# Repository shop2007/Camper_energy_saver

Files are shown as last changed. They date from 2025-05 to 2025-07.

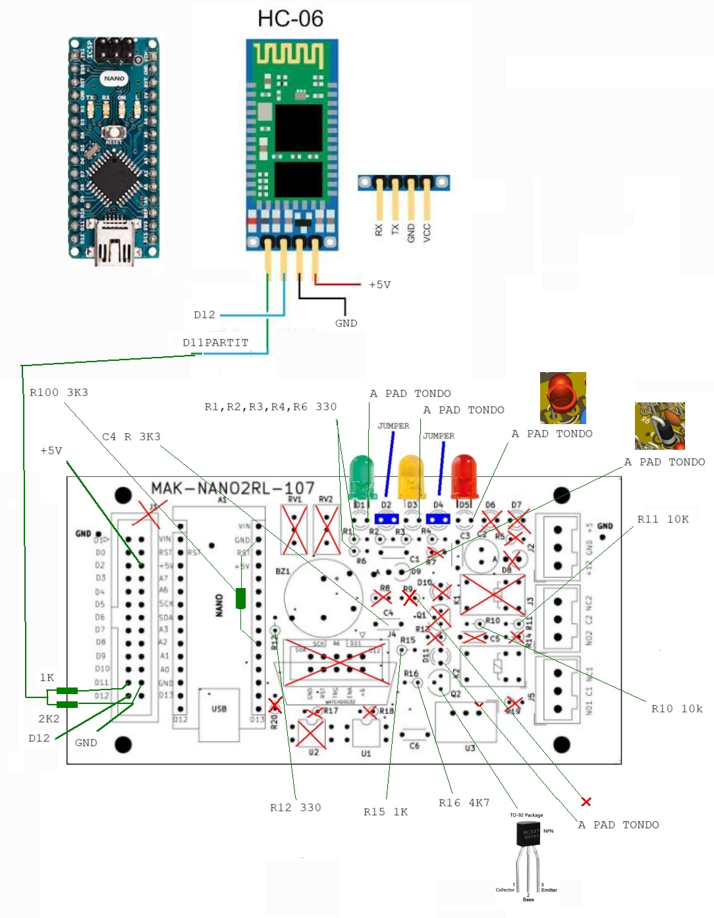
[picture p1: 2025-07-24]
PDF-immagini/MONTAGGIO-V4.jpg

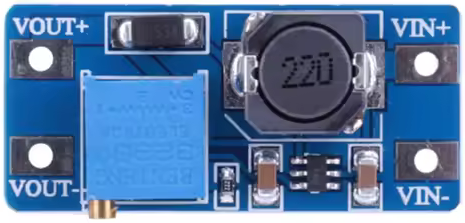
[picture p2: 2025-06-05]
PDF-immagini/MT3608 DC-DC Step-Up Booster.png

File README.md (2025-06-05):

# Camper Energy Saver

**Camper Energy Saver** è un sistema di gestione automatica della ricarica solare nei camper. Il dispositivo controlla la tensione della **batteria servizi** e, quando questa è completamente carica, **connette al charger solare** anche la **batteria di avviamento**, allo scopo di mantenerla completamente carica durante le soste prolungate.
Si possono impostare due soglie che controllano la batteria servizi, quella alta quando al charger solare verrà aggiunta la batteria motore, e quella bassa , quando la stessa viene staccata, per non sottrarre energia alla batteria servizi.

Lo stato del sistema viene trasmesso in tempo reale tramite **Bluetooth (HC-05)** a uno smartphone Android tramite l’app gratuita **“Bluetooth Terminal”**.

---

## ⚙️ Funzionalità principali

- Monitoraggio continuo della **tensione batteria servizi**
- Connessione automatica della carica solare alla batteria motore:
  - Priorità alla batteria servizi
  - Connessione della batteria motore solo quando la batteria servizi è completamente carica
- Segnalazione dello stato via **Bluetooth (HC-05)**
- Compatibilità con l'app Android **Bluetooth Terminal**
- Configurazione soglie tramite cavetto usb (e Arduino IDE) oppure da bluetooth terminal

---

## 🧰 Componenti hardware richiesti

- **Arduino Uno o Nano (ATmega328)**
- **Modulo relè 12V o 5V** (singolo o doppio)
- **Modulo Bluetooth HC-05**
- **Partitore resistivo** per misurare la tensione della batteria servizi
- **Diodi o relè di potenza** per instradare la carica
- **Alimentazione 12V** dal circuito servizi del camper

Al reset si accende semaforo rosso
Quando lampeggia velocemente il semaforo giallo è nel Menù
Quando lampeggia una volta al secondo è in RUN normale

******************************************
## 🧰 PROCEDURA DI CALIBRAZIONE 
- Entrare nel Menu (Nota1) digitando "Menu" ("M" maiuscola ed "u" senza accento)
- Lanciare "7 Calibrazione con tastiera"
- Leggere con un tester preciso la tensione della batteria Servizi
- Agire sulla calibrazione con i tasti t,y,u,i,o,p in modo che La tensione letta su SERVIZI sia uguale alla tensione reale (T-100/Y-10/U-1 I+1/O+10/P+100 bit)
- Ripetere per tensione della batteria AVVIAMENTO con i tasti f,g,h,j,k,l (F-100/G-10/H-1 J+1/K+10/L+100 bit) 
- Salvare uscendo con Q (maiuscolo)
- Resettare con 0

******************************************
## 🧰 MODIFICA DELLE SOGLIE DI INTERVENTO
- Entrare nel Menu (Nota1) digitando "Menu" ("M" maiuscola ed "u" senza accento)
- Lanciare ""8 Taratura soglie da tastiera""
- Modificare la sogia bassa con i tasti t,y,u,i,o,p (T-100/Y-10/U-1 I+1/O+10/P+100 bit)
- Modificare la sogia alta con i tasti f,g,h,j,k,l (F-100/G-10/H-1 J+1/K+10/L+100 bit) 
- Salvare uscendo con Q (maiuscolo)
- Resettare con 0

******************************************
## 🧰 PONTICELLI
- Posizione D4 : default NON INSERITO=10 secondi, INSERITO=1 secondo; Determina il periodo di verifica tensione batteria servizi e azionamento relè
- Posizione D2 : default INSERITO=stampa normale, NON INSERITO=stampa dettagliata per debug  
---

## 🔌 Schema di funzionamento

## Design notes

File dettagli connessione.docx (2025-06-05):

Inserire USB

Aprire Gestione dispositivi ed identificare nelle porte quella corrispondente ad Arduino NANO oppure CH340

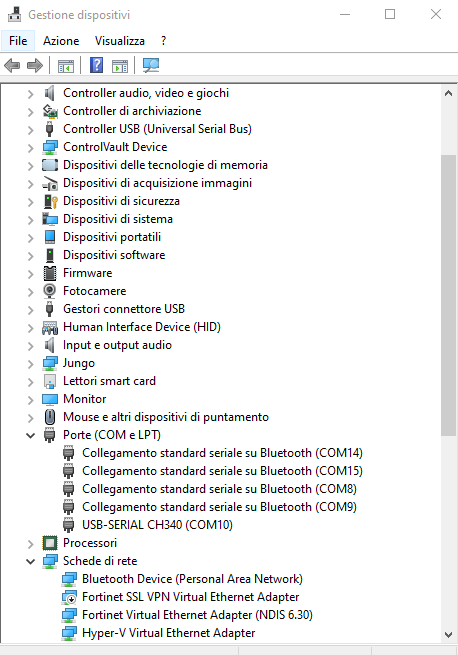
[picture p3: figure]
Immagine che contiene testo, elettronica, schermata, software Il contenuto generato dall'IA potrebbe non essere corretto.

… che nell’esempio è COM10

Aprire PUTTY e selezionare SERIAL, COM10 e speed 115200

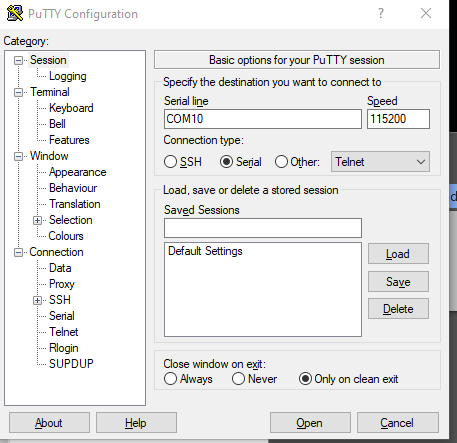
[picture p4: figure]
Immagine che contiene testo, schermata, schermo, software Il contenuto generato dall'IA potrebbe non essere corretto.

… dare open … si vede:

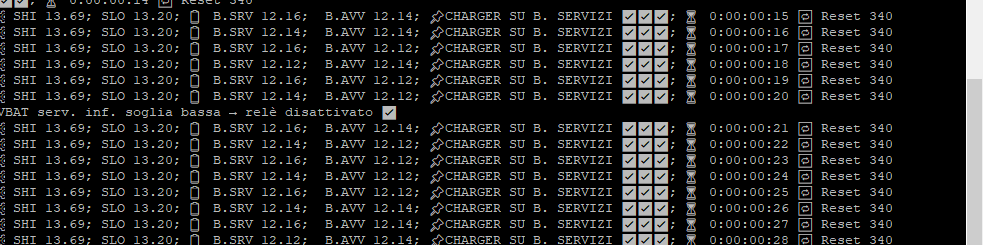
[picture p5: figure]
Immagine che contiene schermata Il contenuto generato dall'IA potrebbe non essere corretto.

TARATURA:

Se Arduino nano è vergine occorre scrivere i parametri di default con il comando del Menù “6 Scrive EEPROM default”

Lanciare il comando: “7 Calibrazione con tastiera”

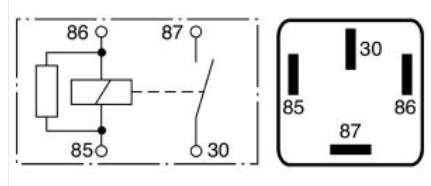
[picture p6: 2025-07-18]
relè auto 12v.png

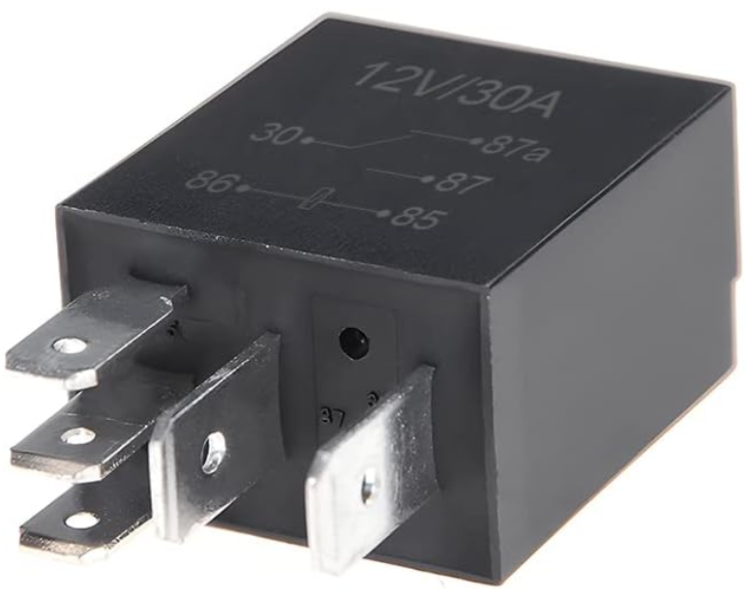
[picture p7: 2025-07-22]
relè auto slim 12v.png

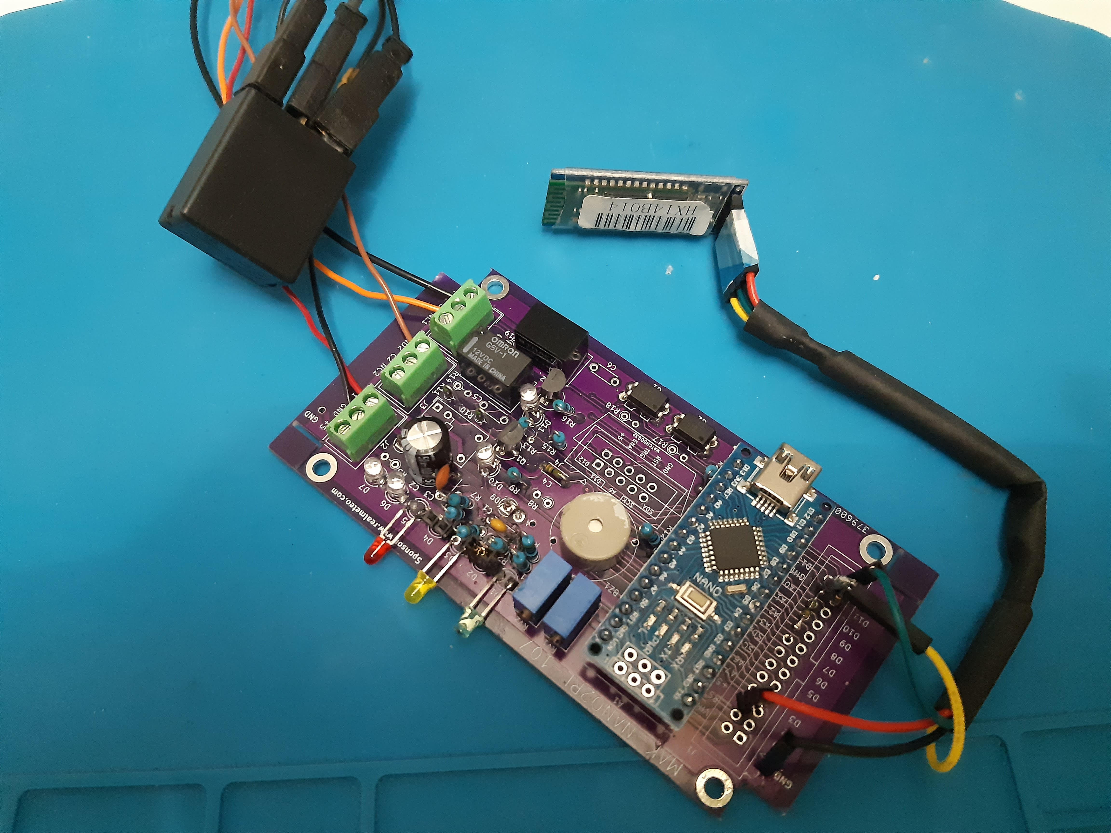
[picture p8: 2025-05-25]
Immagine prototipo.jpg

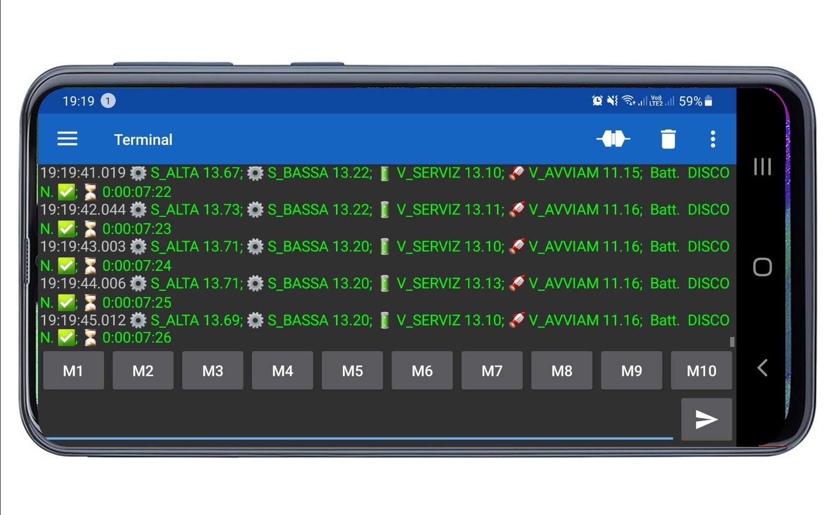
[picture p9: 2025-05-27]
PDF-immagini/bluetooth terminal android 2a.jpg

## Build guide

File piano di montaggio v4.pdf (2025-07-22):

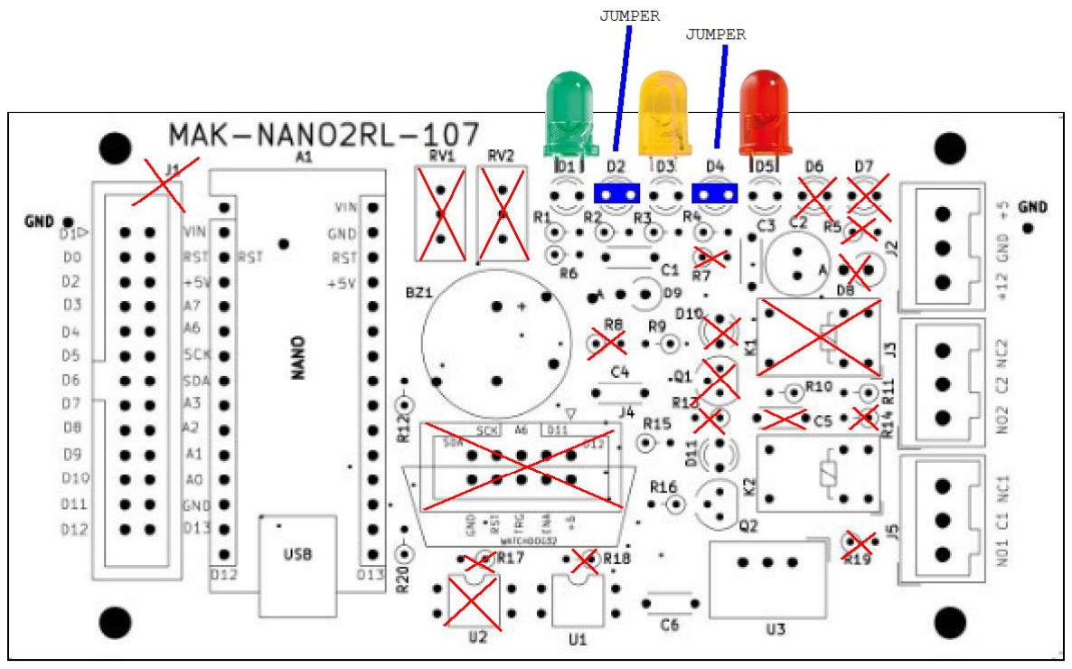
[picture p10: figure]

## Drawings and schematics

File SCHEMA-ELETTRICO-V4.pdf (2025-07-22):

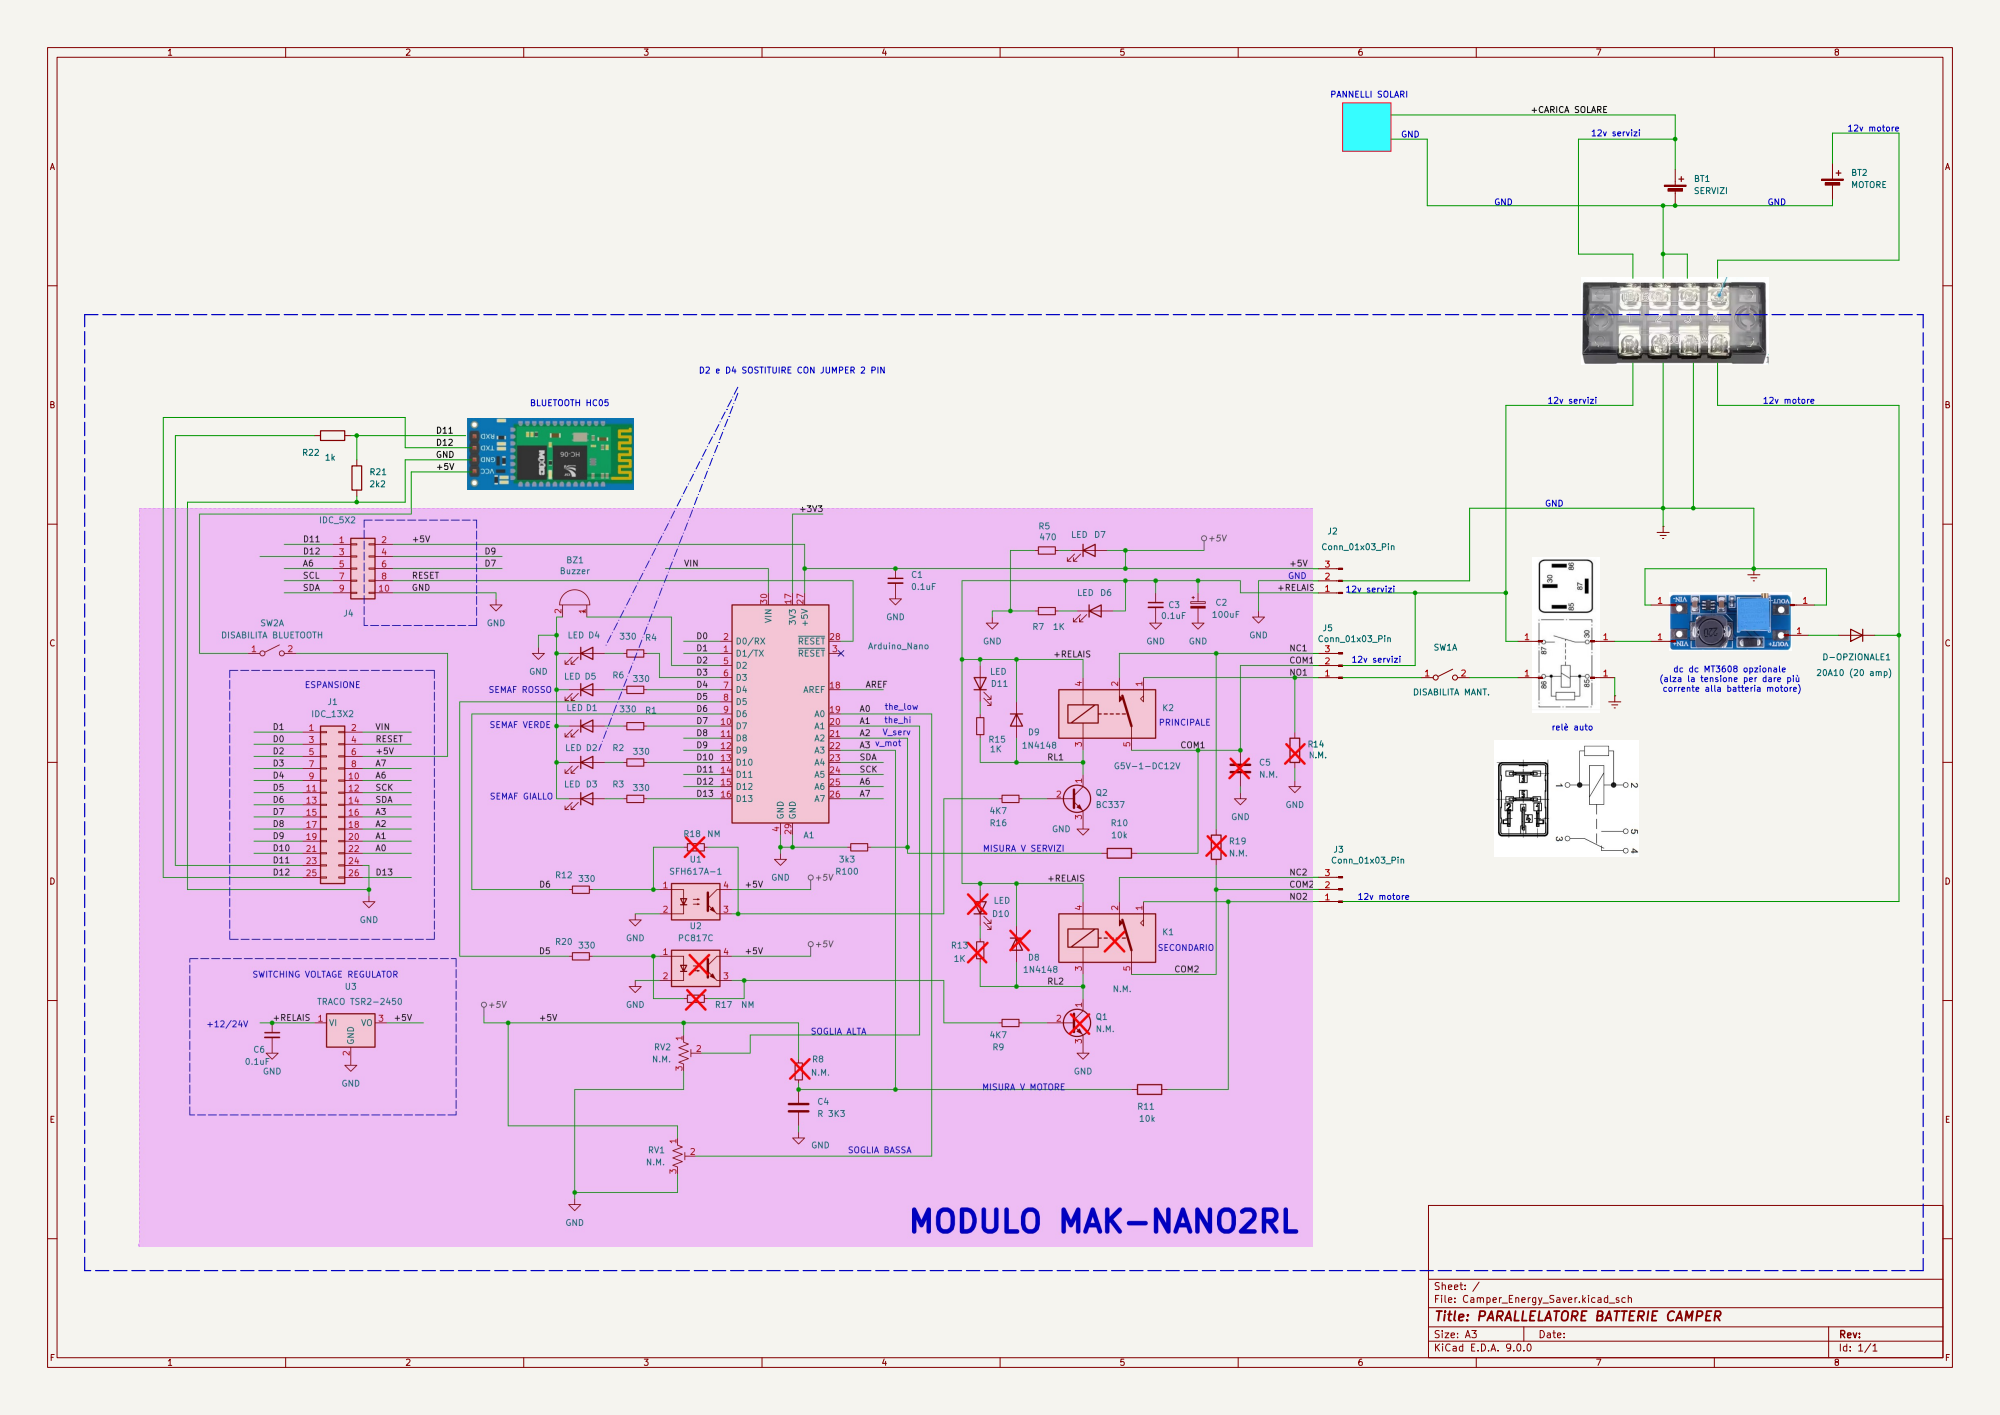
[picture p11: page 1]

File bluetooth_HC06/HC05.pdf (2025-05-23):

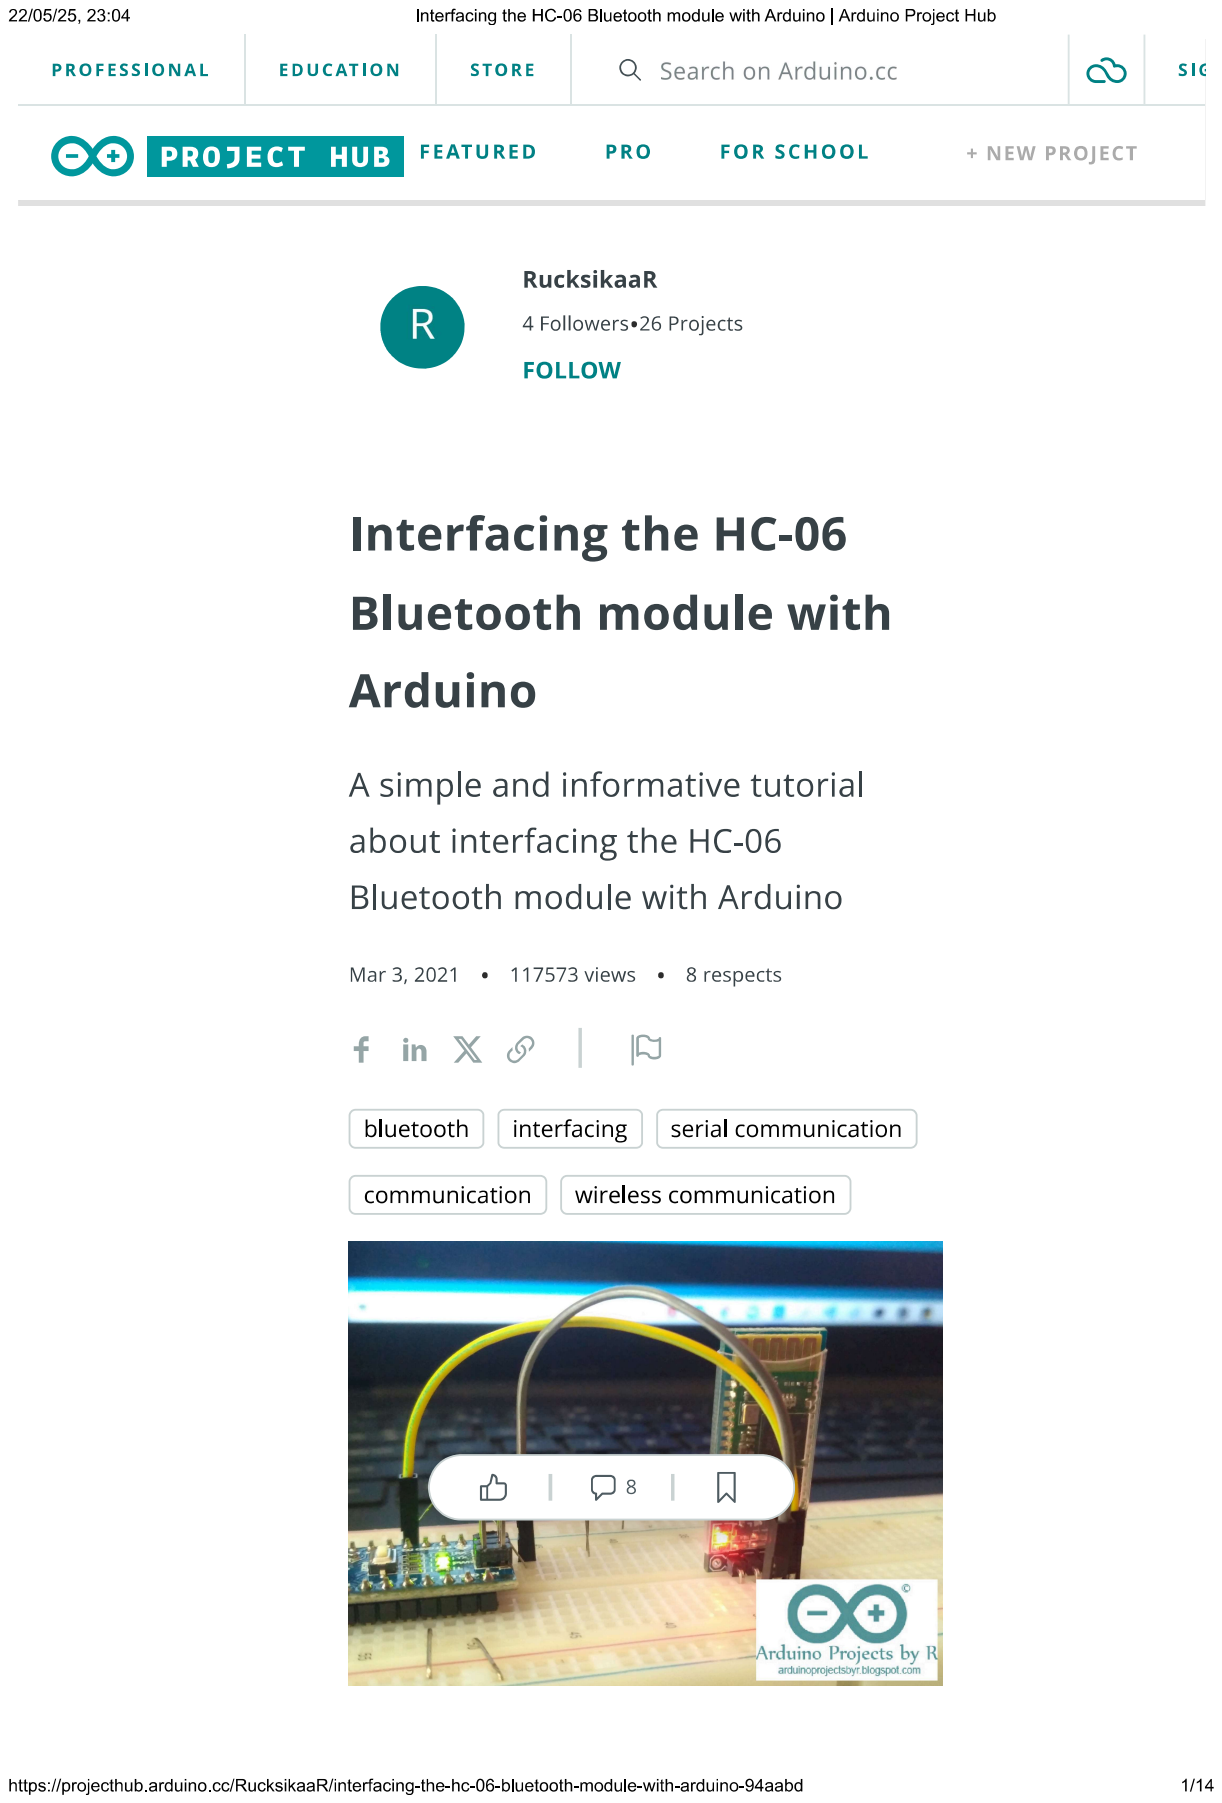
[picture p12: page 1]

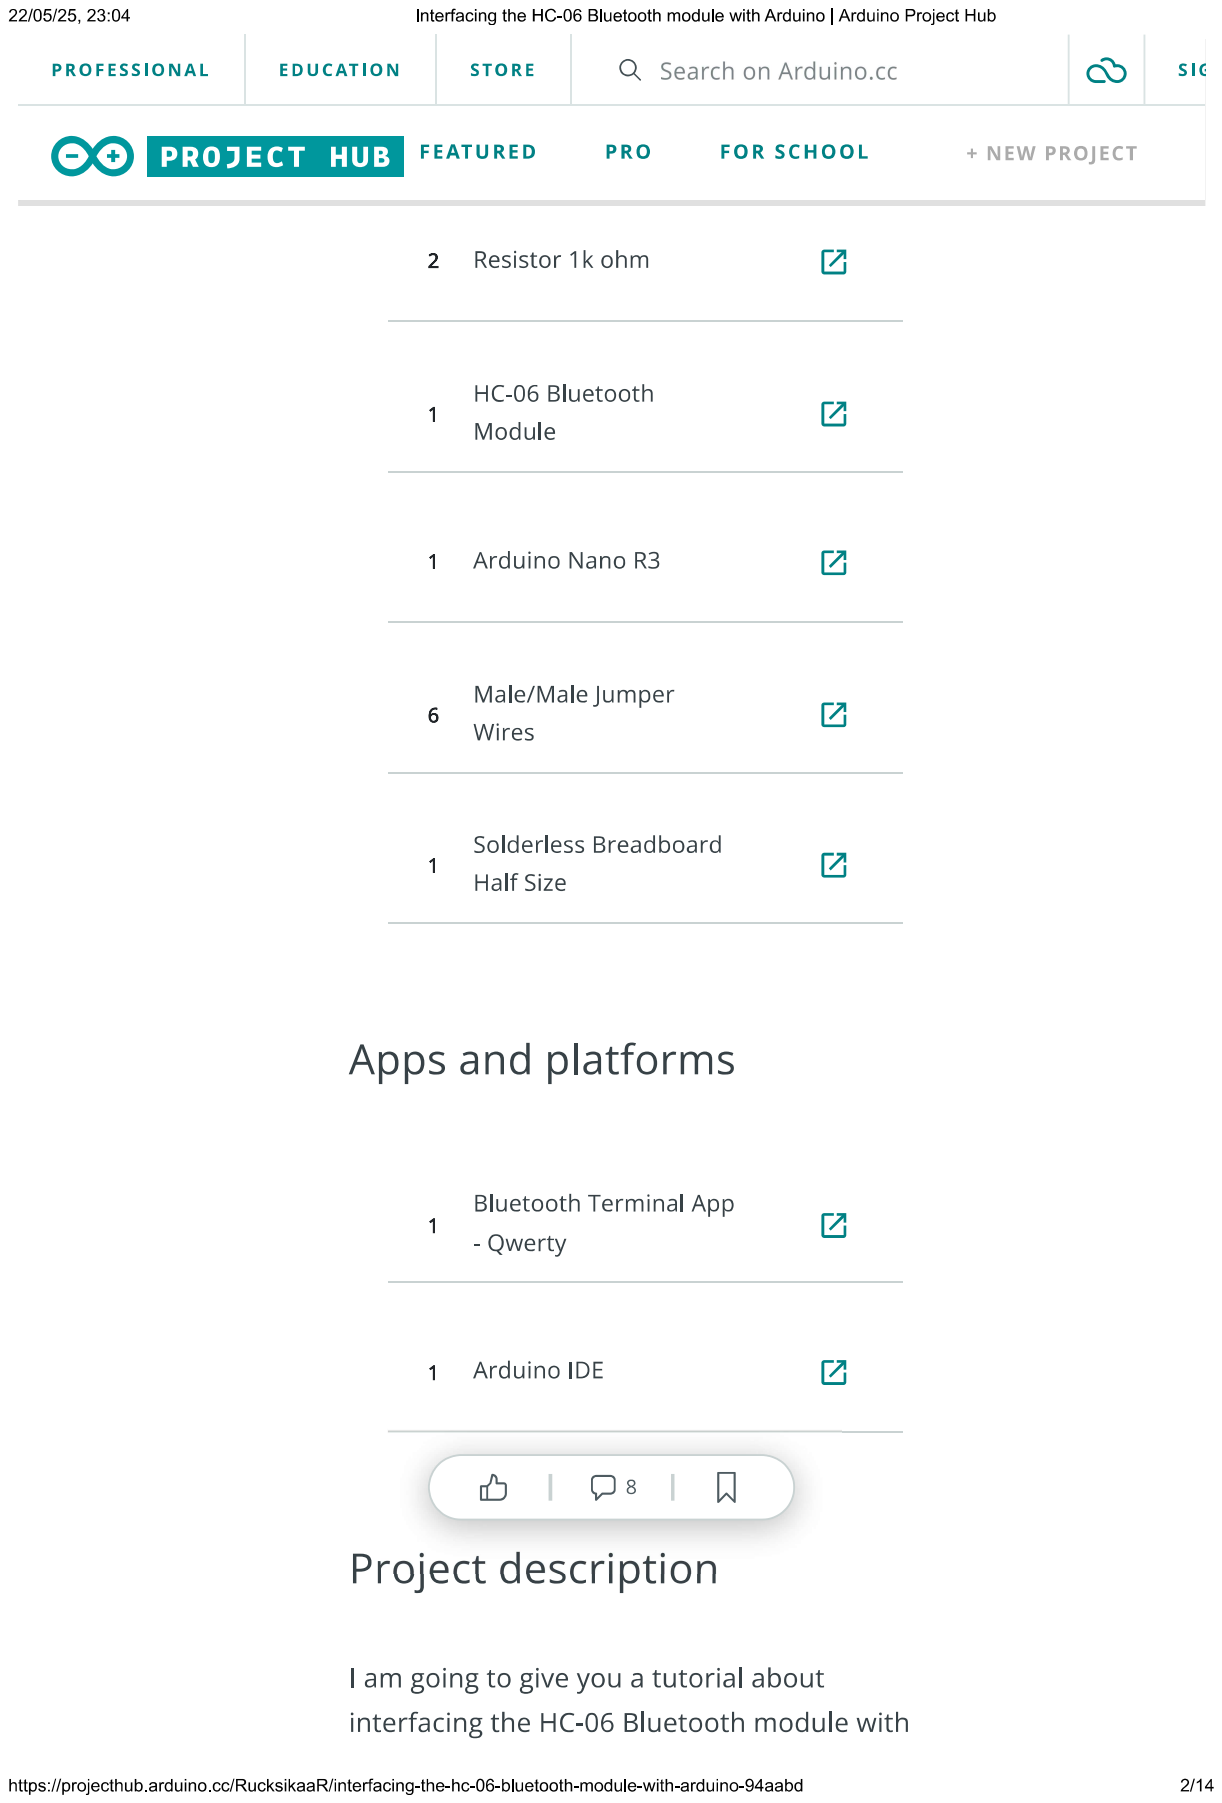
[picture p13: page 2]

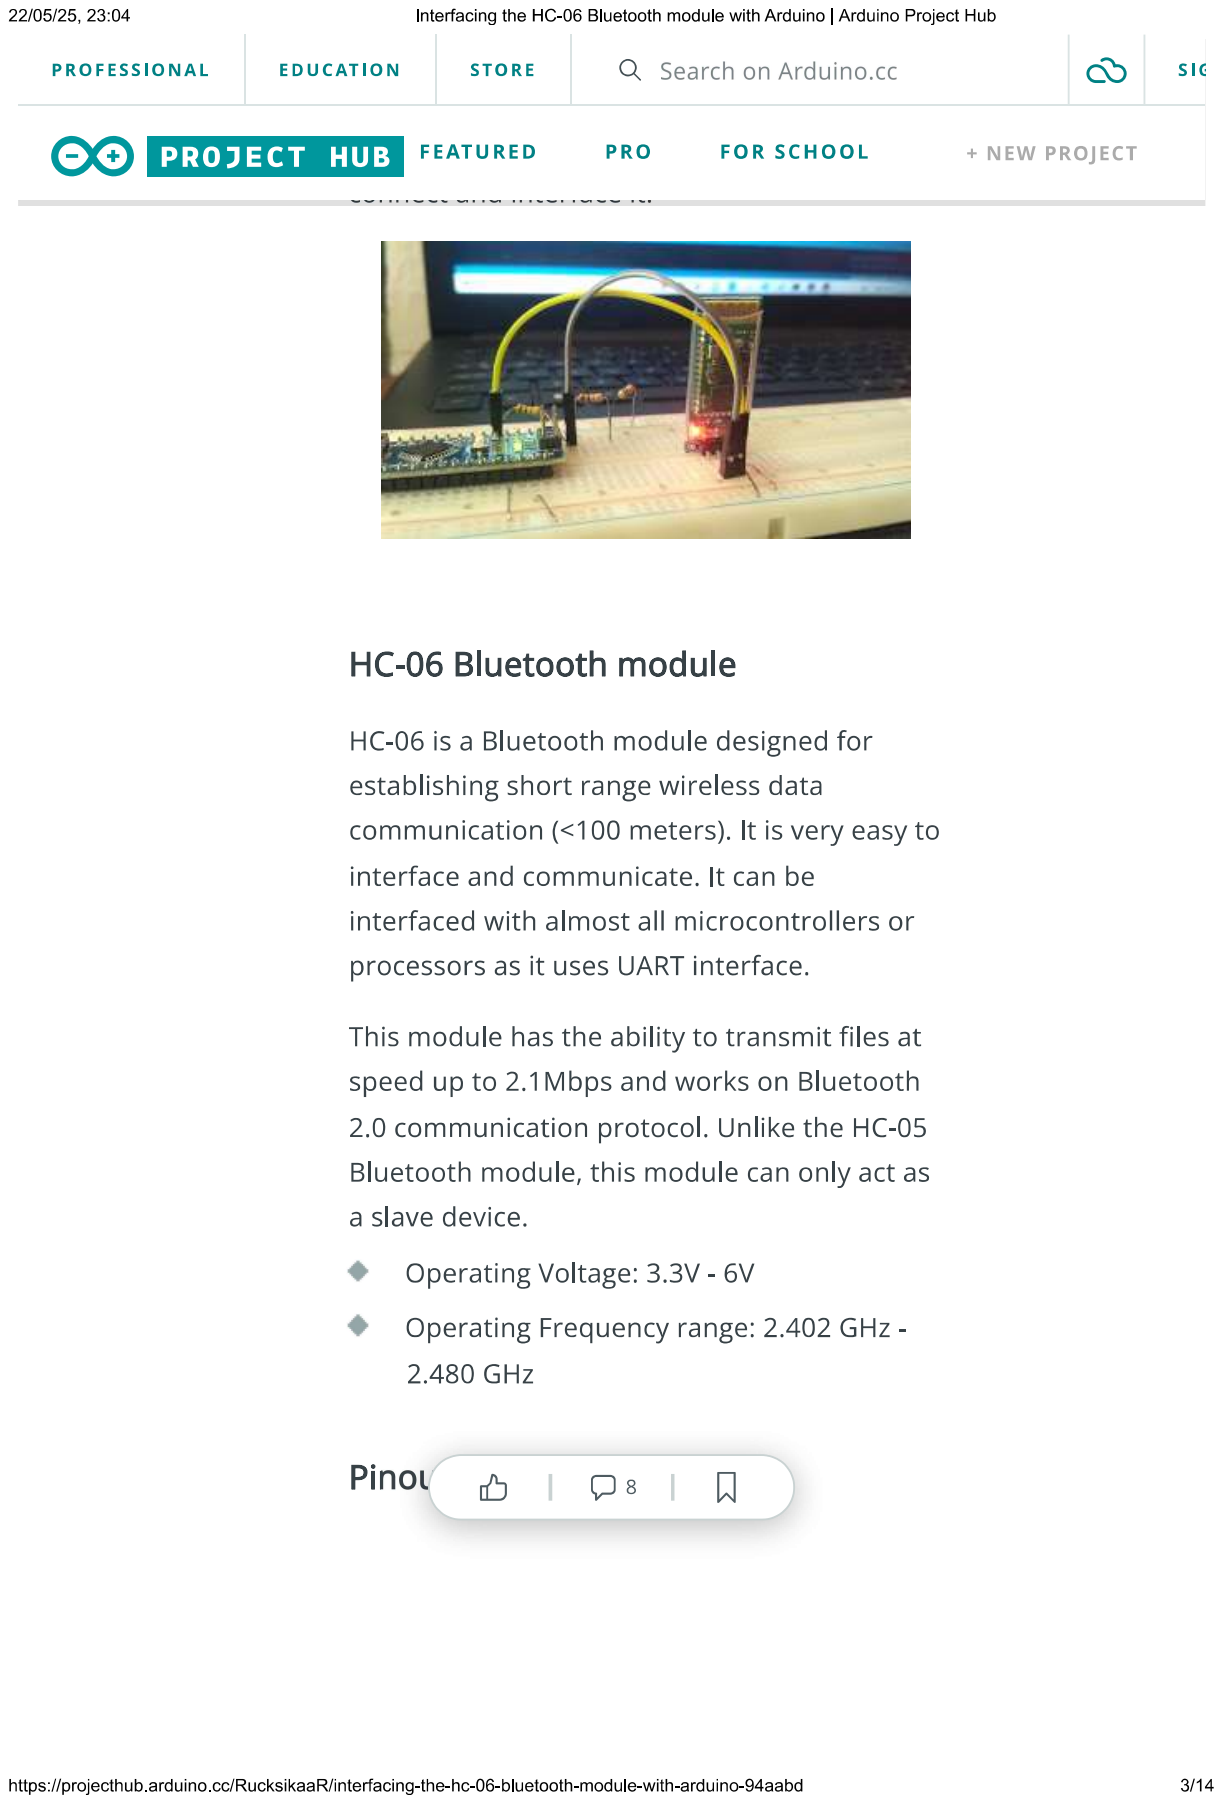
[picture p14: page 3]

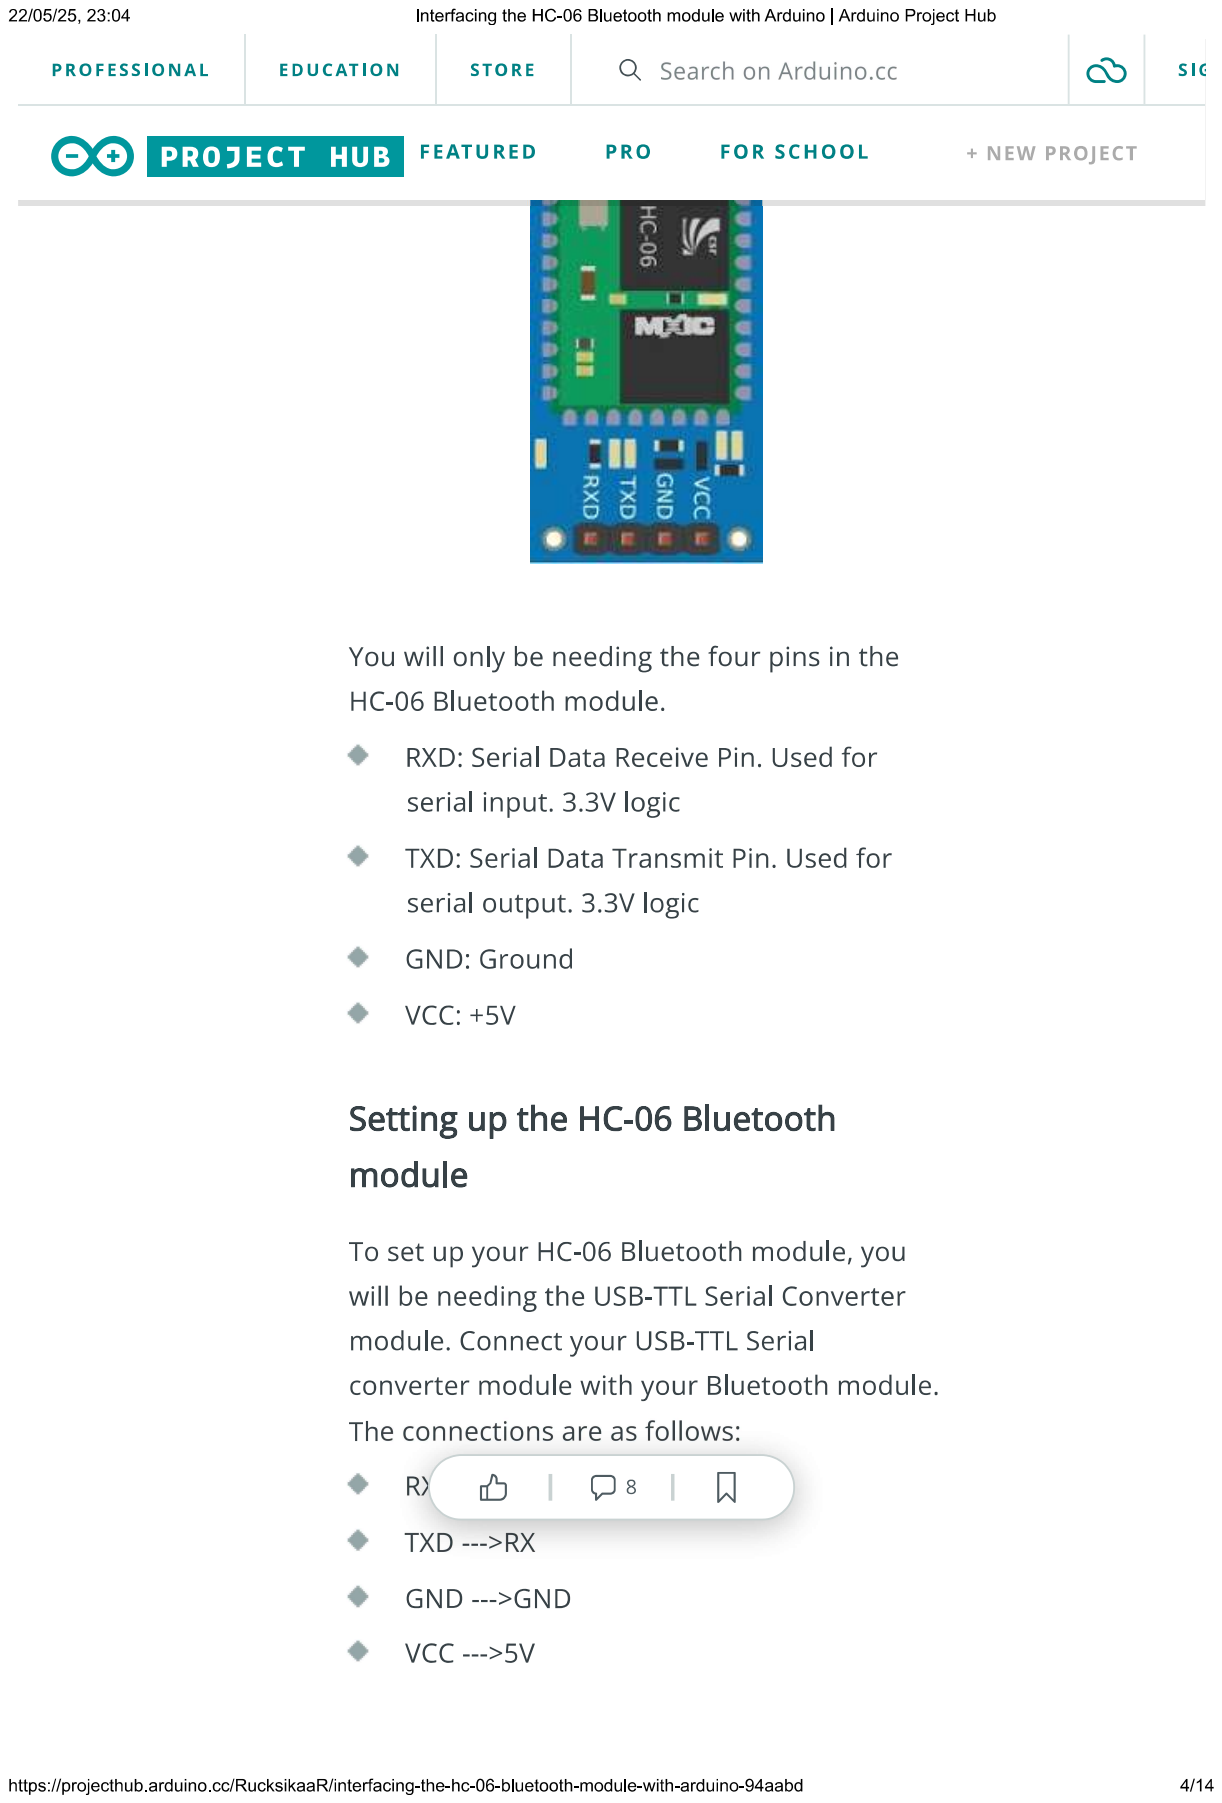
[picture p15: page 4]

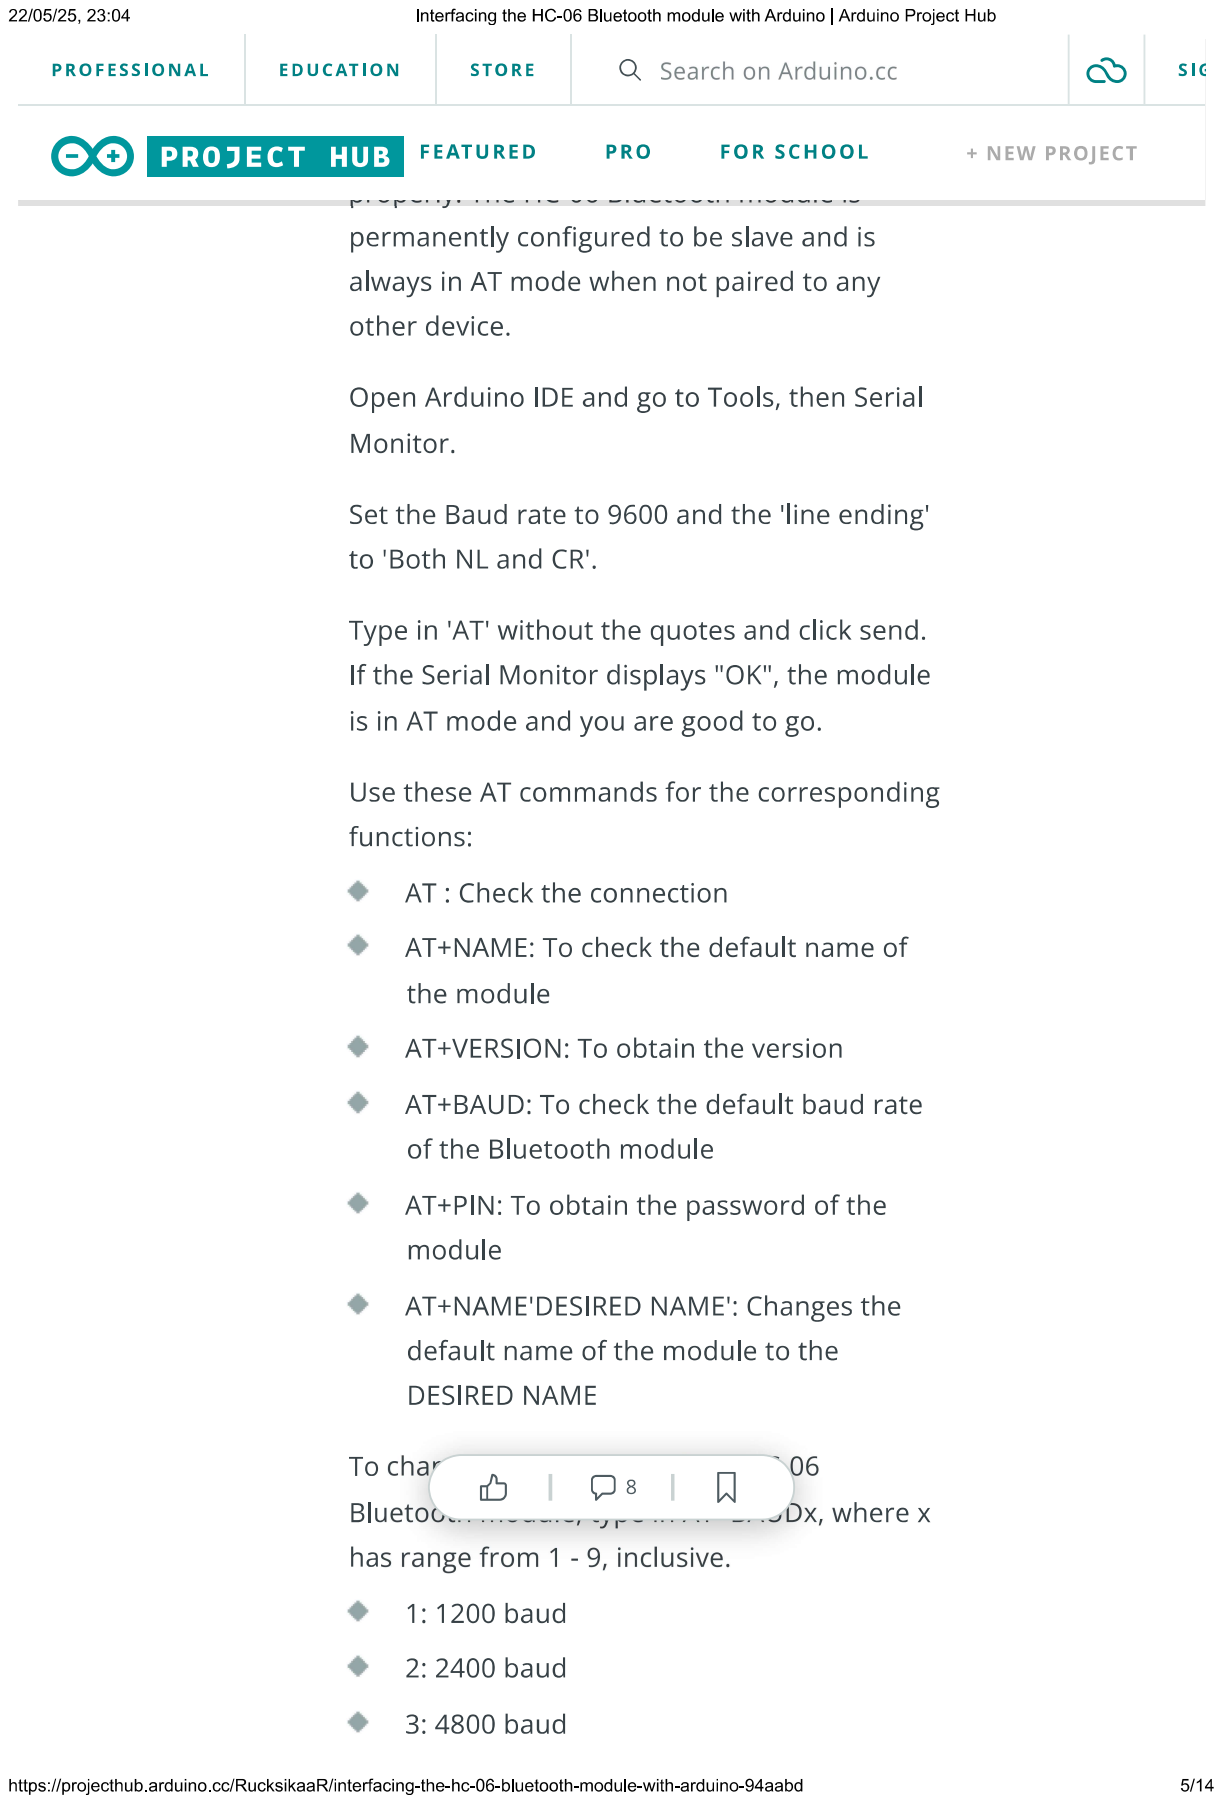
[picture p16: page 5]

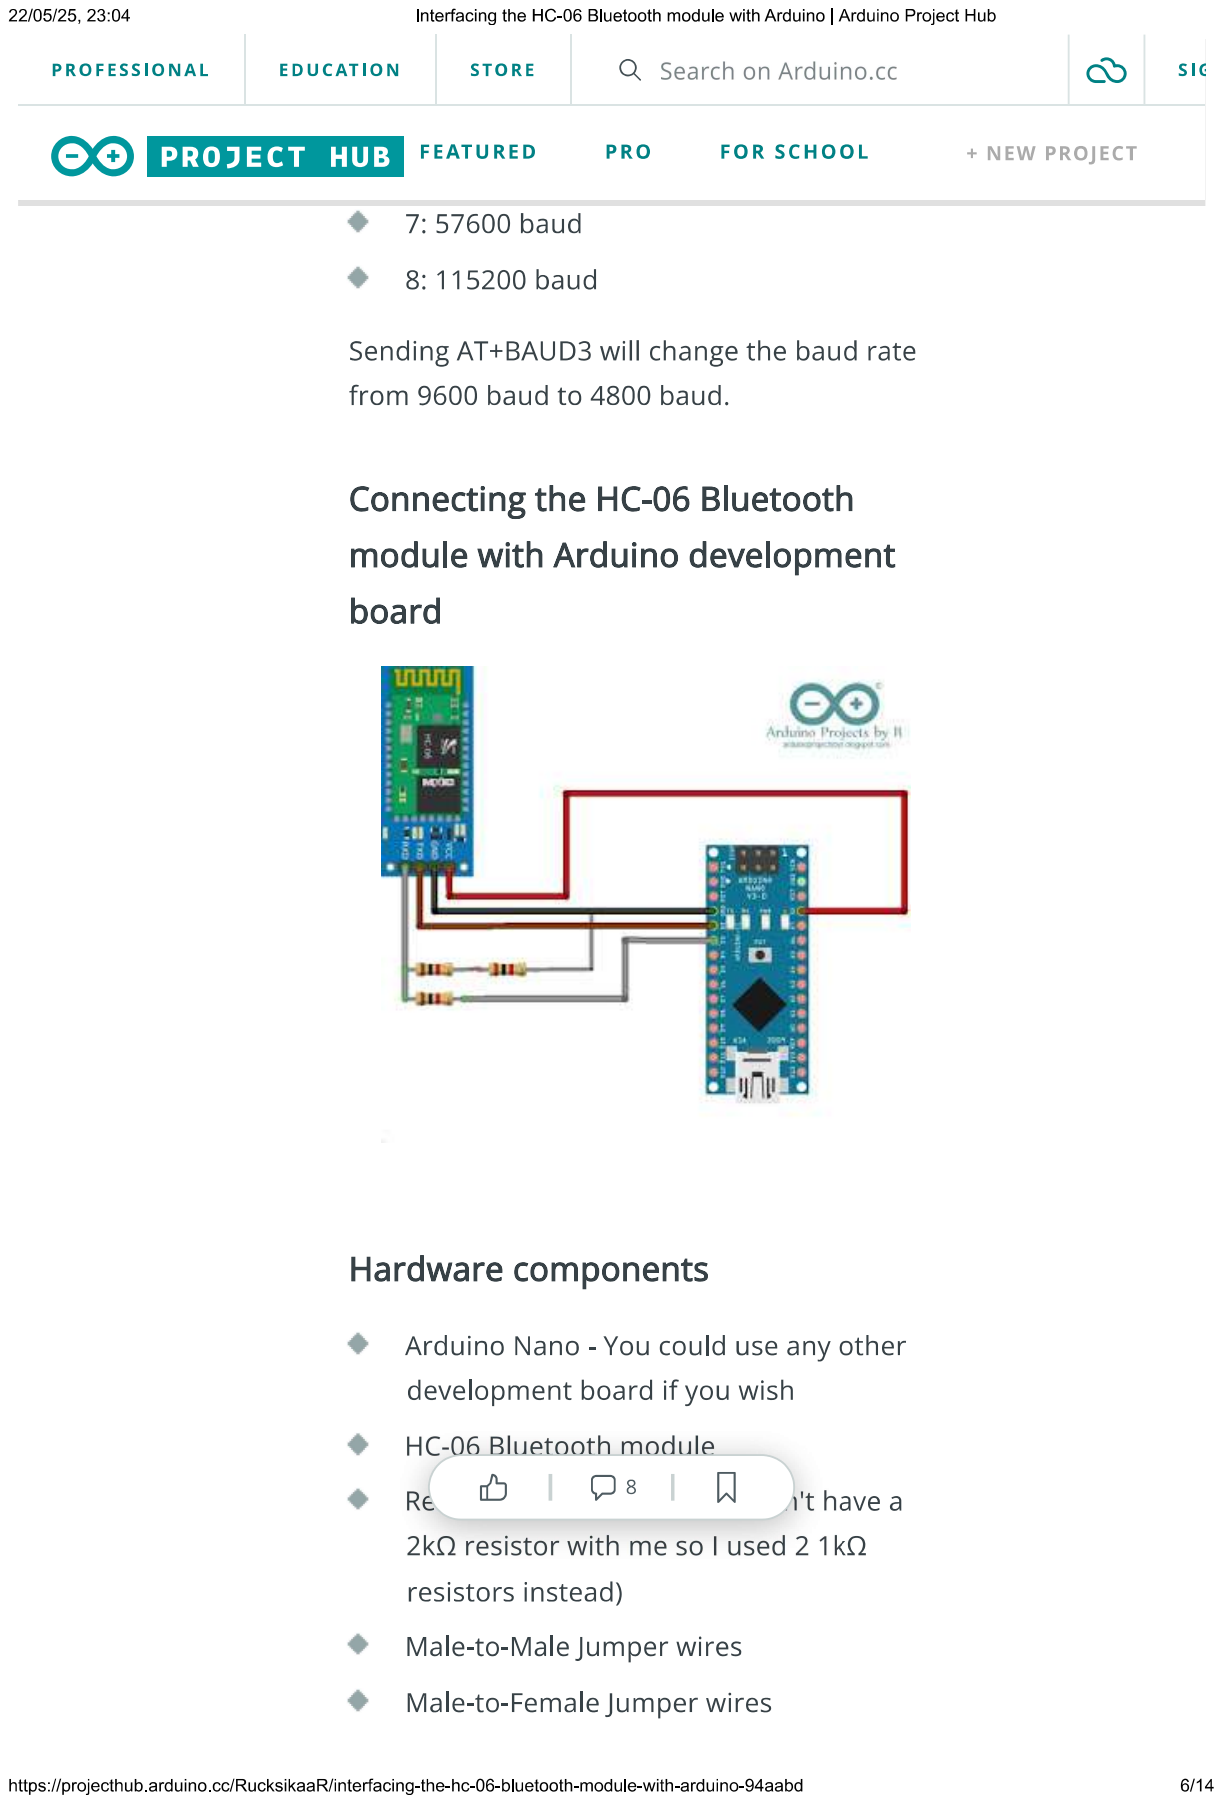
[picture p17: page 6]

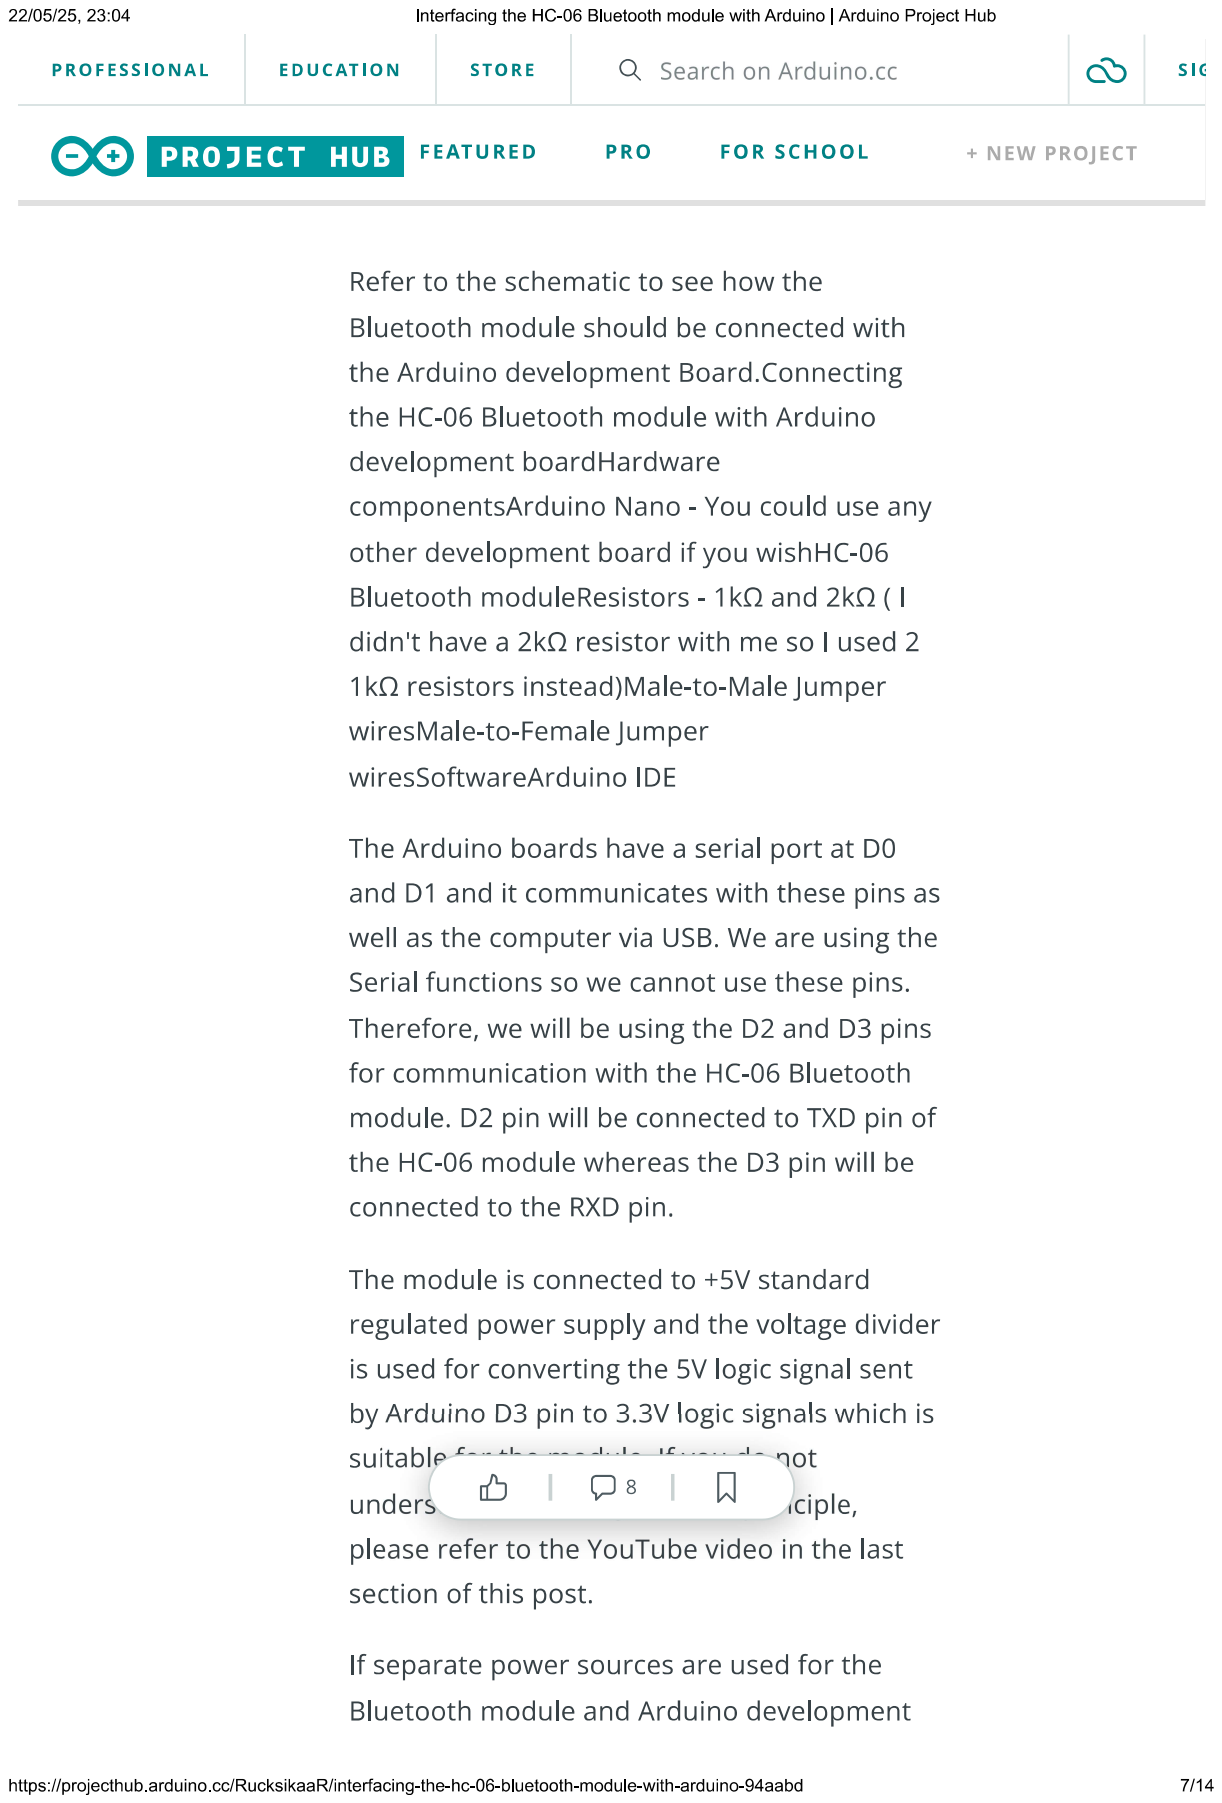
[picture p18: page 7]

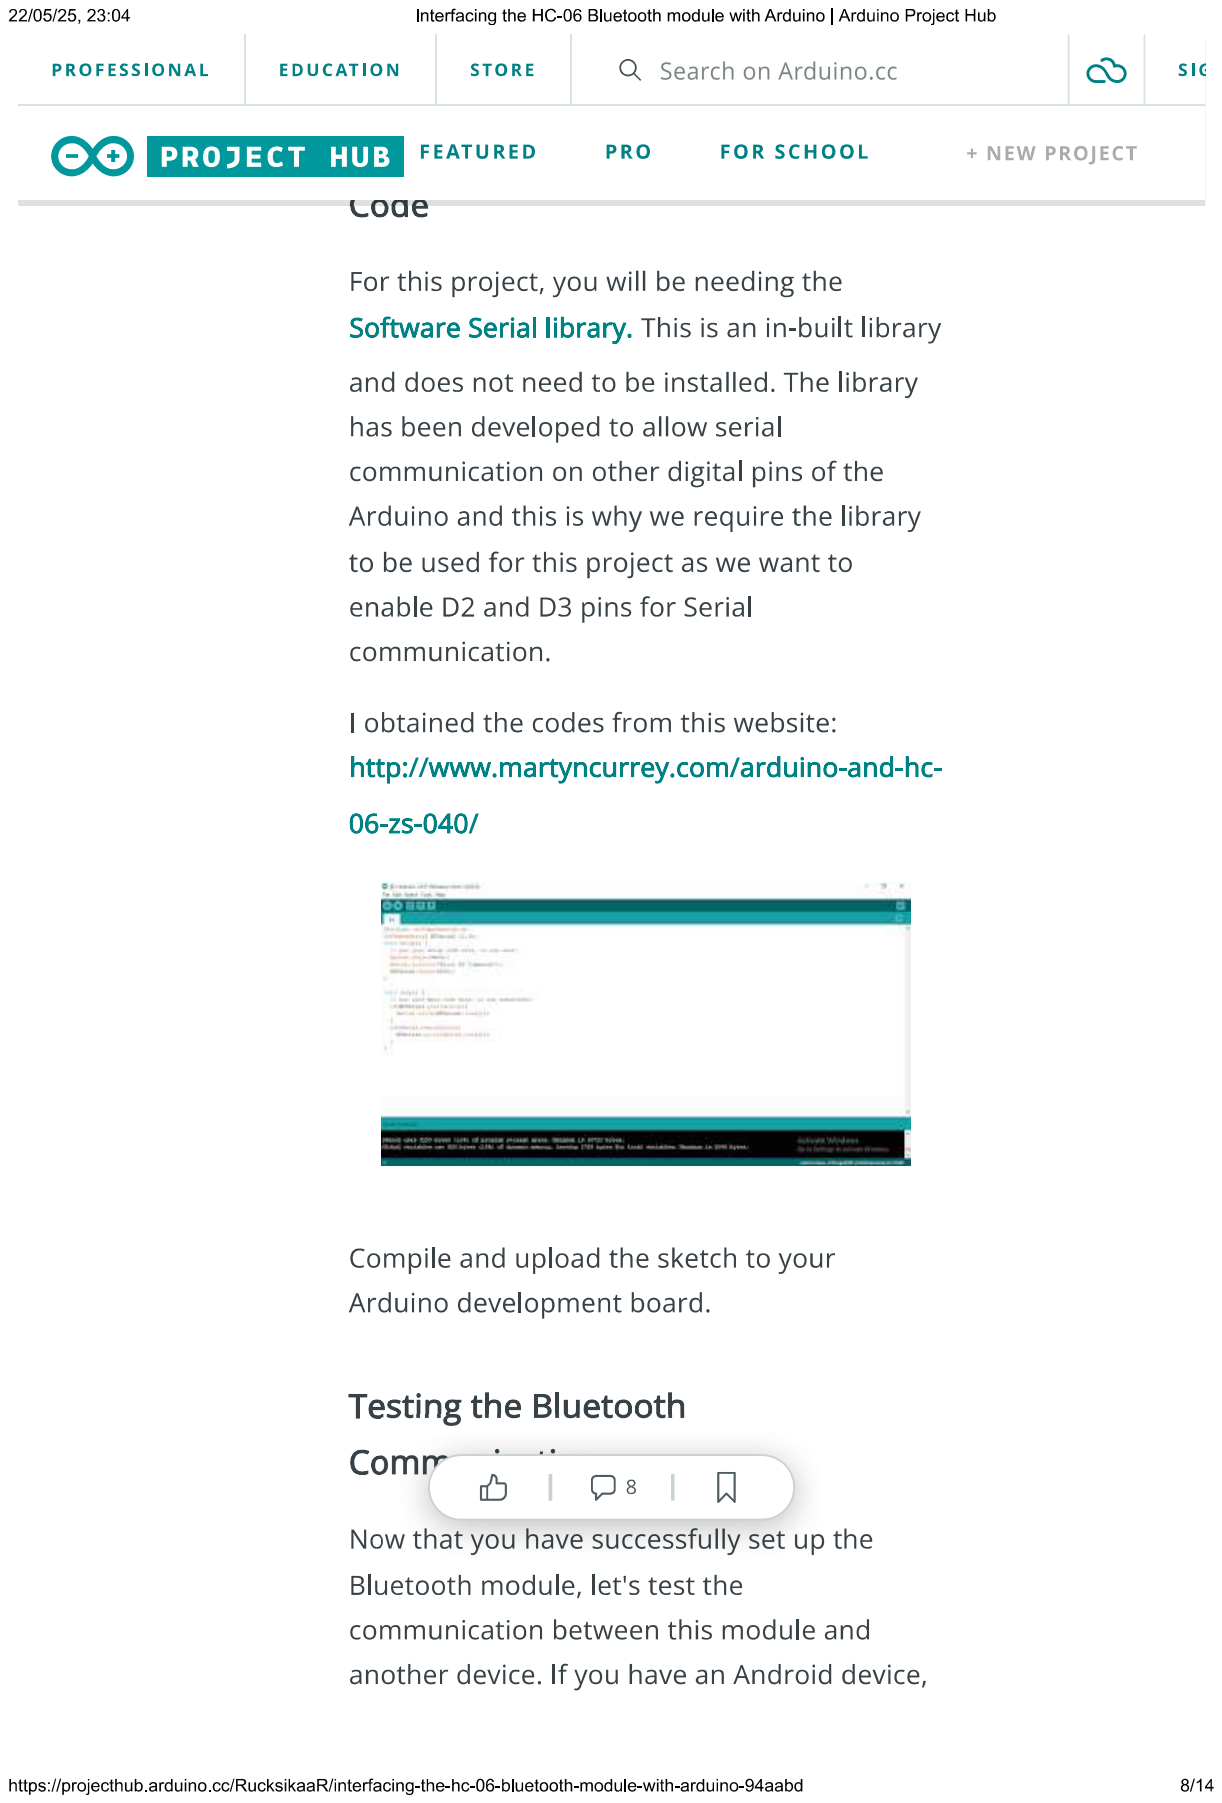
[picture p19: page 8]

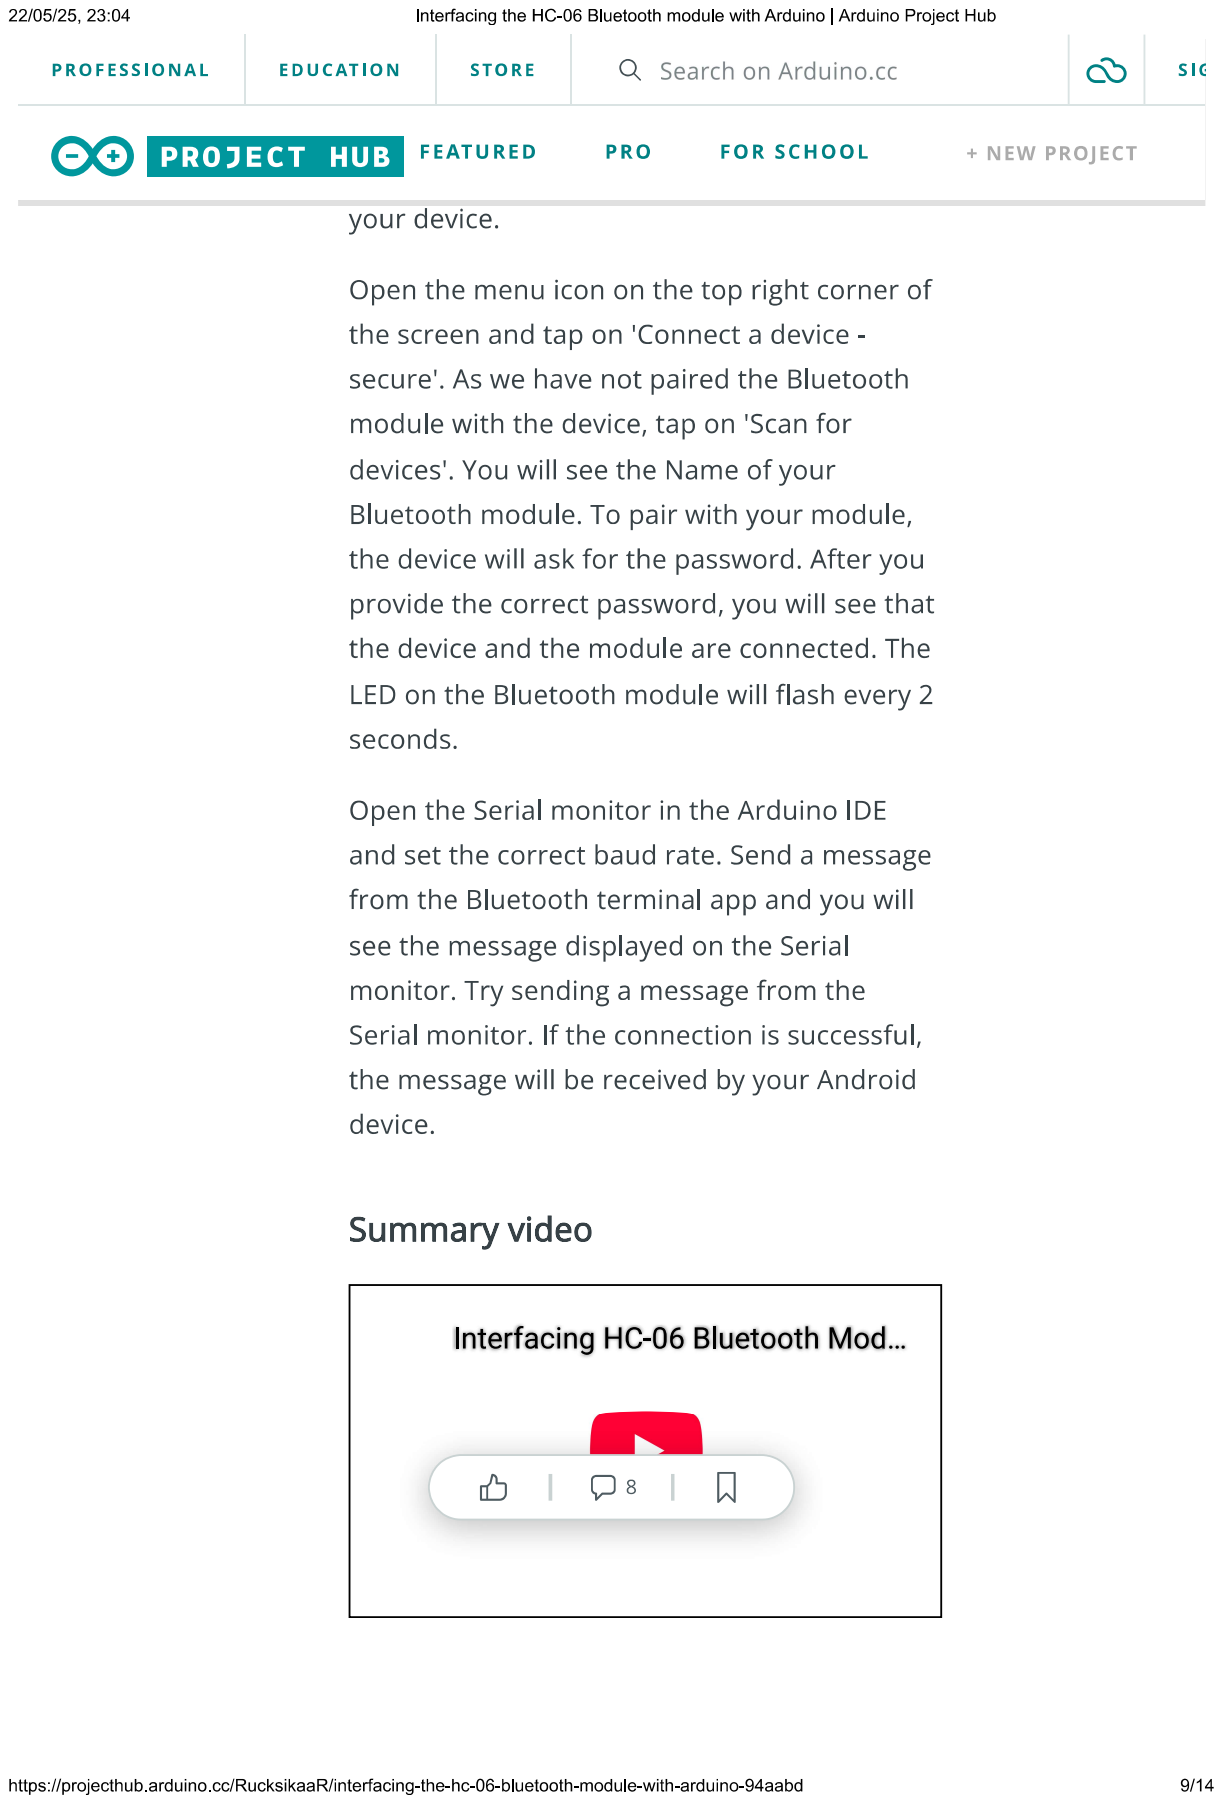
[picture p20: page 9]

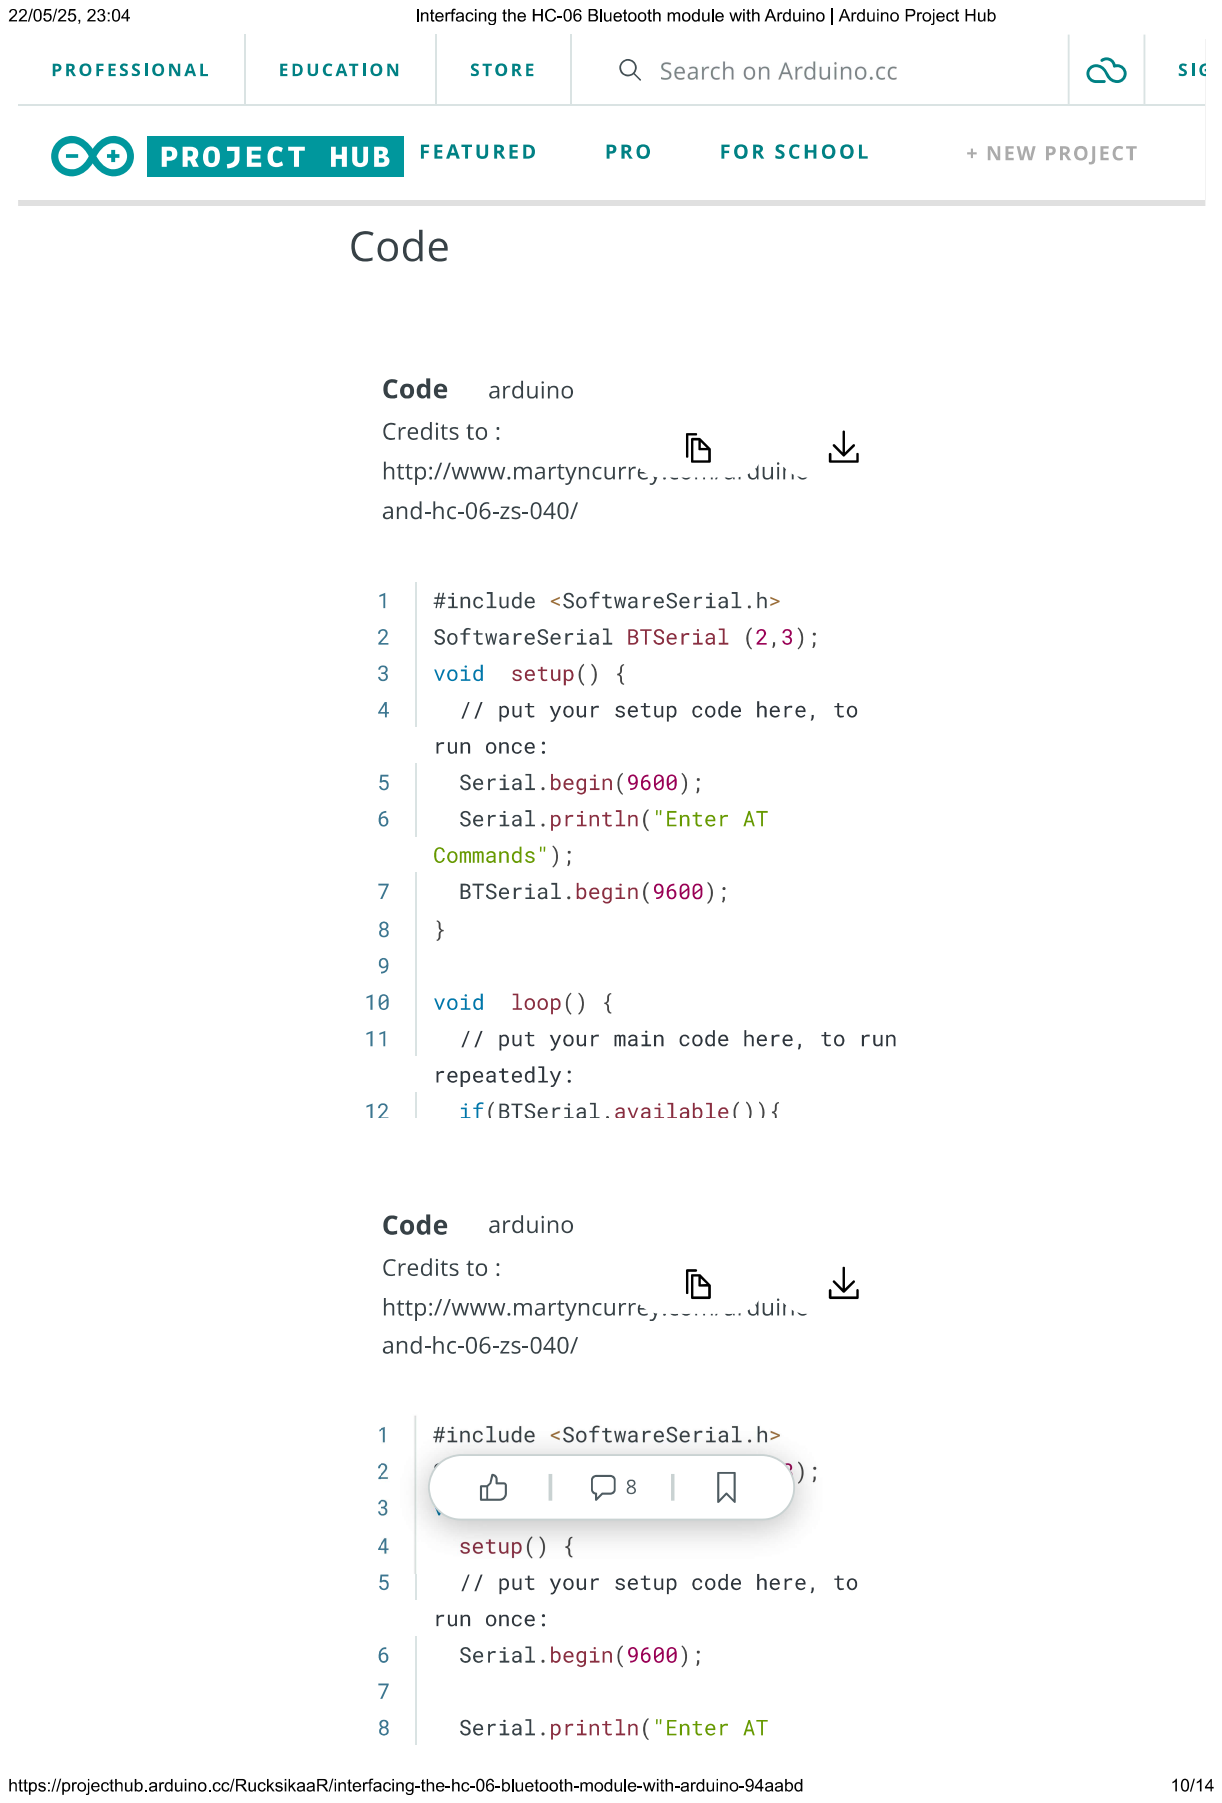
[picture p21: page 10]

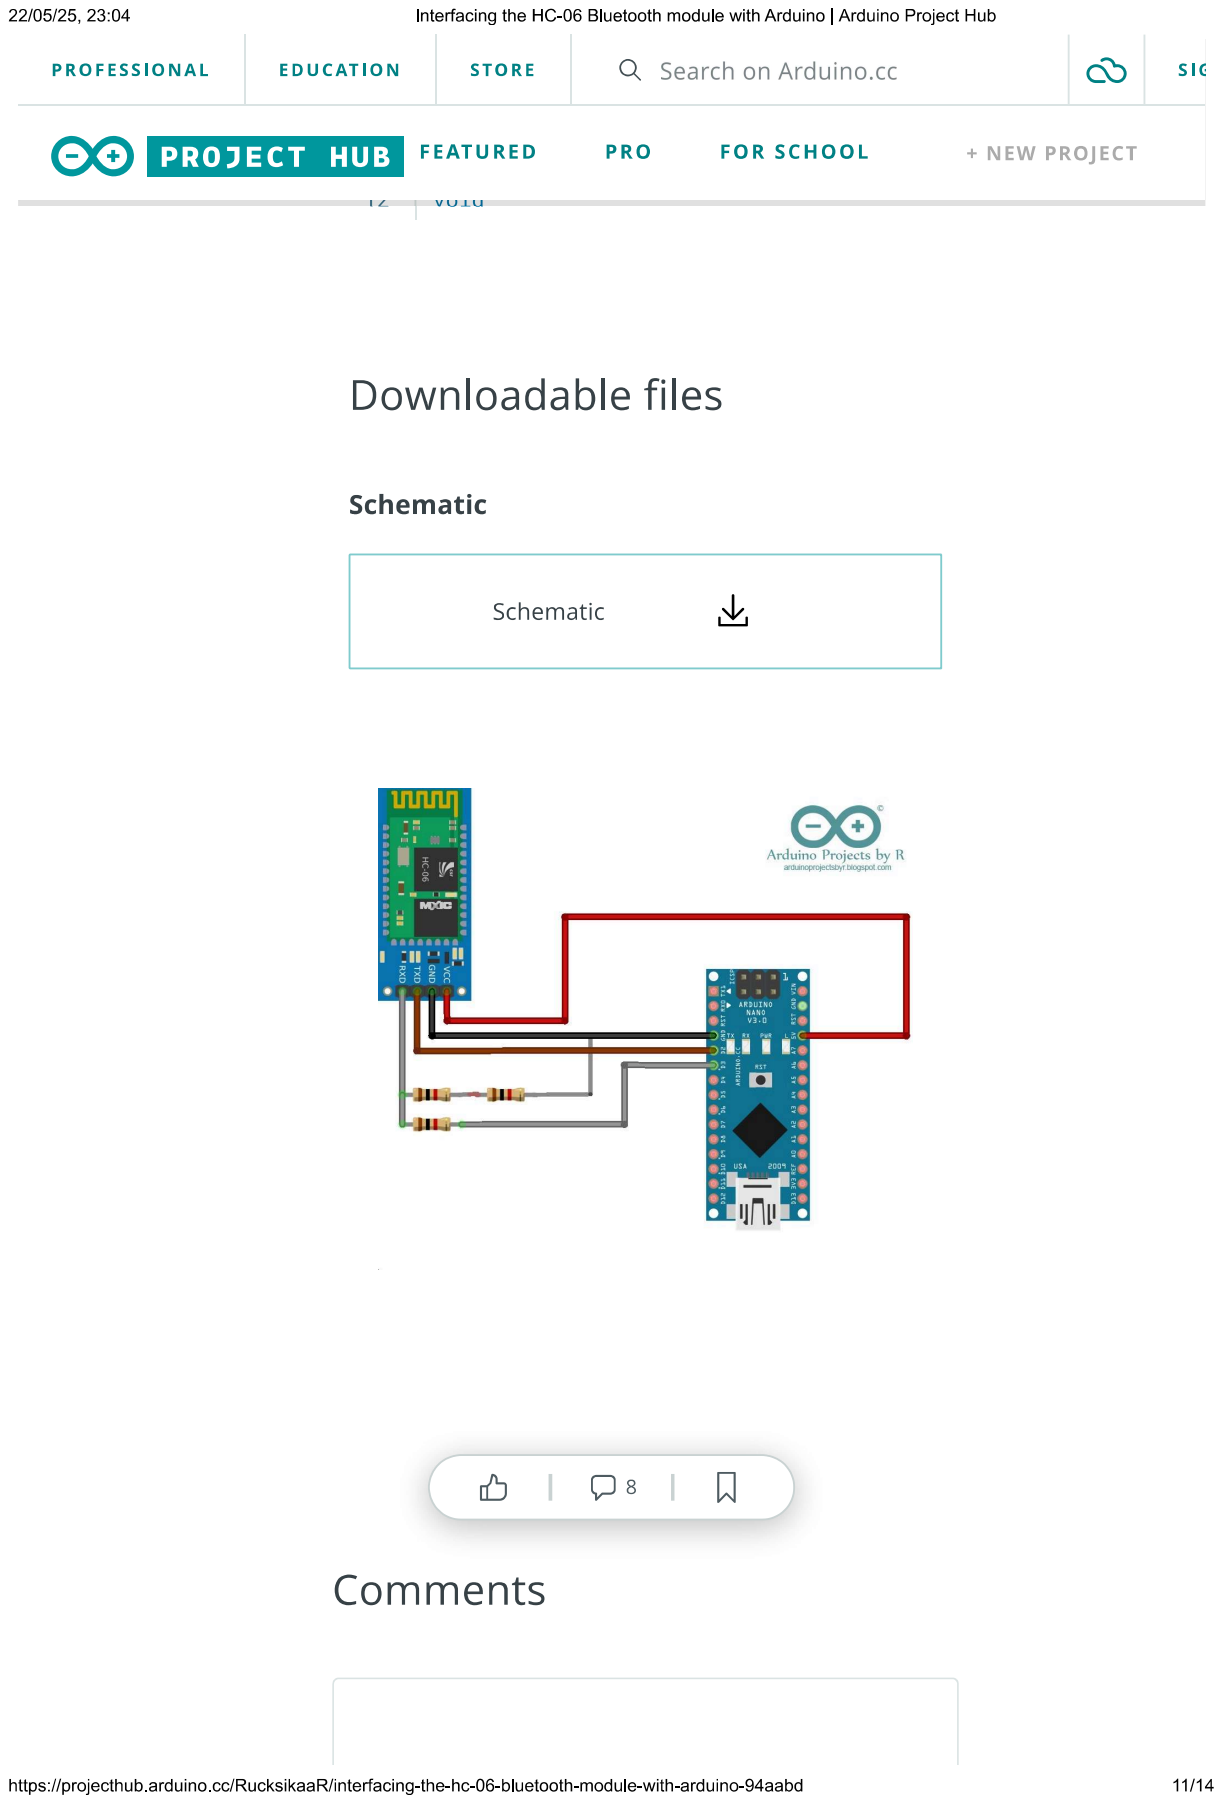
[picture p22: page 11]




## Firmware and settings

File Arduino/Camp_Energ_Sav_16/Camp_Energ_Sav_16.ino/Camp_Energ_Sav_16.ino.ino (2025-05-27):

String Versione = "Camp_Energ_Sav_16";
/*
14 aggiunto calibrazione da tastiera
15 aggiunto contatore di reset
16 aggiunto taratura soglie da tastiera

Al reset si accende semaforo rosso
Quando lampeggia velocemente il semaforo giallo è nel Menù
Quando lampeggia una volta al secondo è in RUN normale

due beep tornato ai servizi
tre bip passato al morore

bluetoot lampeggia: attende connessione
bluetooth fisso connesso

jumper D4 sinistro = rele ogni secondo, se inseriro, oppure ogni 10 secondi
jumper d2 se inserito stampa normale se inserito, oppure stampa anche adc per debug

******************************************
PROCEDURA DI CALIBRAZIONE
nota: i trimmer sono usati per calibrare e poi torneranno a fare la funzione di soglia alta e soglia bassa
- Entra nel Menu
- lancia 6 Calibrazione
- Leggere con un teste preciso la tensione Servizi
- Regolare il trimmer di destra RV1 in modo che La tensione letta su Calib SRV sia uguale alla tensione reale
- Ripetere per tensione motore
- Salvare uscendo con Q (maiuscolo)
- Resettare con 0
- A questo punto occorre tarare i due trimmer per la soglia desiderata 
  Trimmer RV2 sinistra = soglia bassa
  Trimmer RV1 destra = soglia alta


HARDWARE MAK_NANO2RL-107

arduino
D0  RISERVATO USB
D1  RISERVATO USB
D2  BUZZER
D3  LED D4 JUMPER AZIONA OGNI SECONDO (SE INSERITO)
D4  LED D5 SEMAFORO ROSSO
D5  
D6  RELAY
D7  LED D1 SEMAFORO VERDE
D8  
D9  
D10 LED D2 JUMPER STAMPA DETTAGLIATA (SE TOLTO)
D11 BLUETOOTH
D12 BLUETOOTH
D13 LED D3 SEMAFORO GIALLO
A0  
A1  
A2  
A3  
A4  
A5  
A6  
A7  





*/







#include <avr/wdt.h>
#include <avr/io.h>
#include <EEPROM.h>
#include <SoftwareSerial.h>
SoftwareSerial bluetooth(12, 11); // RX, TX
bool Beep_Status = false; //beep al cmbio status
bool Silenzioso = true;
// Pin definitions
const int RELAY_PIN = 6;

const int BUZZER_PIN = 2;

const int JUMPER_LEDD4 = 3; //relè ogni secondo se inserito
const int JUMPER_LEDD2 = 10; //stampa estesa se inserito


const int LED_SEM_VERDE_PIN = 7;
const int LED_SEM_GIALLO_PIN = 13;
const int LED_SEM_ROSSO_PIN = 4;



const int TRIMMER_SOGLIA_ALTA_PIN = A0;
const int TRIMMER_SOGLIA_BASSA_PIN = A1;

int ADC_BAT_SERVIZI_PIN = A2;
int ADC_BAT_MOTORE_PIN = A3;






bool Test_a_banco = false; //inverte vbat servizi e motore
bool debug= false; // 


// Timer variables
unsigned long previousMillis = 0;
//unsigned long previous60sMillis = 0;
const unsigned long interval1s = 1000;



//OROLOGIO
unsigned int Secondi = 0;
unsigned int Minuti = 0;
unsigned int Ore = 0;
unsigned int Giorni = 0;

unsigned int ContaSecondi = 0; //mai azzerato
unsigned int SecondiVerificaBatterie = 10;       // Intervallo modificabile
unsigned int lastEsecuzione = 0;           // Ultimo valore di Secondi usato per chiamare la funzione


// --- Contatore di reset ---
unsigned int resetCount = 0; // Contatore di reset come unsigned long

// Coefficienti di calibrazione (caricati da EEPROM)
float Calibrazione_servizi;
float Calibrazione_motore;

//-------------------
// Indirizzi EEPROM
const int EEPROM_ADDR_volt_calibrata_srv = 0;
const int EEPROM_ADDR_volt_calibrata_mot = EEPROM_ADDR_volt_calibrata_srv + sizeof(float);
// Definisci l'indirizzo per il contatore di reset dopo i dati esistenti
const int EEPROM_RESET_ADDRESS = EEPROM_ADDR_volt_calibrata_mot + sizeof(float); 
// Questo metterà il contatore a partire dall'indirizzo 8 (4 per il primo float + 4 per il secondo float)
  // Salva in EEPROM: seguendo gli indirizzi già occupati da due float
const int EEPROM_ADDR_soglia_bassa = EEPROM_RESET_ADDRESS + sizeof(int);  // es. da 12
const int EEPROM_ADDR_soglia_alta  = EEPROM_ADDR_soglia_bassa + sizeof(int); // es. da 14
//----------------------




// Partitore valori
const float R1 = 10000.0;
const float R2 = 3300.0;
const float VREF = 5.0;

int adc_servizi_bit; // = analogRead(ADC_BAT_SERVIZI_PIN);
int adc_motore_bit; // = analogRead(ADC_BAT_MOTORE_PIN);
int Soglia_Bassa_Bit; // 
int Soglia_Alta_Bit; // 
float Soglia_Bassa_Volt; // = Soglia_Bassa_Bit * VREF / 1023.0 ;
float Soglia_Alta_Volt; // = Soglia_Alta_Bit * VREF / 1023.0 ;
float batt_servizi_volt; // = adc_servizi_bit * VREF / 1023.0 * (R1 + R2) / R2;
float batt_motore_volt; // = adc_servizi_bit * VREF / 1023.0 * (R1 + R2) / R2;



/*
contatore wdog in eeprom eliminato, non funziona, viene azzerato dal boot di arduino
// EEPROM addresses for 2-byte counter
const int EEPROM_ADDR_LOW = 0;
const int EEPROM_ADDR_HIGH = 1;
*/

bool Relay_Status = false;
String inputString = "";         // a String to hold incoming data
bool stringComplete = false;  // whether the string is complete
bool ExitFromMenu = false;
int Cestino;
int ledState = LOW;             // ledState used to set the LED
const int ledPin =  LED_BUILTIN;// the number of the LED pin
const long interval = 250;           // interval at which to blink (milliseconds)

const long customParseIntTimeout = 1000;
//xxxxxxxxxxxxxxxxxxxxxxxxxxxxxxxxxxxxxxxxxxxxxxxxxxxxxxxxxxxxxxxxxxxxxxxxxxxxxxxxxxxxxxxxxxxxxxxxxx

// --- prototipi



//xxxxxxxxxxxxxxxxxxxxxxxxxxxxxxxxxxxxxxxxxxxxxxxxxxxxxxxxxxxxxxxxxxxxxxxxxxxxxxxxxxxxxxxxxxxxxxxxxx

// Funzione per mappare da intero a float
float mapFloat(long x, long in_min, long in_max, float out_min, float out_max) {
  return (float)(x - in_min) * (out_max - out_min) / (float)(in_max - in_min) + out_min;
}



//xxxxxxxxxxxxxxxxxxxxxxxxxxxxxxxxxxxxxxxxxxxxxxxxxxxxxxxxxxxxxxxxxxxxxxxxxxxxxxxxxxxxxxxxxxxxxxxxxx
//xxxxxxxxxxxxxxxxxxxxxxxxxxxxxxxxxxxxxxxxxxxxxxxxxxxxxxxxxxxxxxxxxxxxxxxxxxxxxxxxxxxxxxxxxxxxxxxxxx
//xxxxxxxxxxxxxxxxxxxxxxxxxxxxxxxxxxxxxxxxxxxxxxxxxxxxxxxxxxxxxxxxxxxxxxxxxxxxxxxxxxxxxxxxxxxxxxxxxx
//xxxxxxxxxxxxxxxxxxxxxxxxxxxxxxxxxxxxxxxxxxxxxxxxxxxxxxxxxxxxxxxxxxxxxxxxxxxxxxxxxxxxxxxxxxxxxxxxxx
//xxxxxxxxxxxxxxxxxxxxxxxxxxxxxxxxxxxxxxxxxxxxxxxxxxxxxxxxxxxxxxxxxxxxxxxxxxxxxxxxxxxxxxxxxxxxxxxxxx

void dumpEEPROM(int startAddress, int numBytes) {
  for (int i = 0; i < numBytes; i++) {
    // Stampa l'indirizzo all'inizio di ogni riga di 16 byte
    if (i % 16 == 0) {
      if (i != 0) {
        Serial.println(); // Nuova riga dopo ogni blocco di 16 byte
      }
      // Formatta l'indirizzo con zeri iniziali (es. "0000", "0010")
      if ((startAddress + i) < 16) Serial.print("000");
      else if ((startAddress + i) < 256) Serial.print("00");
      else if ((startAddress + i) < 4096) Serial.print("0");
      Serial.print(startAddress + i, HEX);
      Serial.print(" ");
    }

    // Legge il byte dalla EEPROM
    byte data = EEPROM.read(startAddress + i);

    // Stampa il byte in formato esadecimale con zero iniziale se necessario
    if (data < 0x10) {
      Serial.print("0");
    }
    Serial.print(data, HEX);
    Serial.print(" ");
  }
  Serial.println(); // Assicura una nuova riga alla fine
}
//xxxxxxxxxxxxxxxxxxxxxxxxxxxxxxxxxxxxxxxxxxxxxxxxxxxxxxxxxxxxxxxxxxxxxxxxxxxxxxxxxxxxxxxxxxxxxxxxxx

void Eeprom_Diagnostica(){
  Serialprint2("ADR Calbraz. Servizi: ");Serialprint2(EEPROM_ADDR_volt_calibrata_srv);Serialprint2(" -> ");Serialprint2ln(Calibrazione_servizi);
  Serialprint2("ADR Calbraz. Motore: ");Serialprint2(EEPROM_ADDR_volt_calibrata_mot);Serialprint2(" -> ");Serialprint2ln(Calibrazione_motore);
  Serialprint2("ADR Counter Reset: ");Serialprint2(EEPROM_RESET_ADDRESS);Serialprint2(" -> ");Serialprint2ln(resetCount);
  Serialprint2("ADR Soglia Bassa: ");Serialprint2(EEPROM_ADDR_soglia_bassa);Serialprint2(" -> ");Serialprint2ln(Soglia_Bassa_Bit);
  Serialprint2("ADR Soglia Alta: ");Serialprint2(EEPROM_ADDR_soglia_alta);Serialprint2(" -> ");Serialprint2ln(Soglia_Alta_Bit);

  //EEPROM.put(EEPROM_RESET_ADDRESS, 200); 
  dumpEEPROM(0, 64); // Stampa le prime 64 celle a partire dall'indirizzo 0
 
}





//xxxxxxxxxxxxxxxxxxxxxxxxxxxxxxxxxxxxxxxxxxxxxxxxxxxxxxxxxxxxxxxxxxxxxxxxxxxxxxxxxxxxxxxxxxxxxxxxxx


void CalibrazioneSoglieKeyboard() {
  Serialprint2ln(F("== Modalità Calibrazione Soglie (da tastiera) =="));
  Serialprint2ln(F("Soglia BASSA: t/y/u (dim) - i/o/p (aum)"));
  Serialprint2ln(F("Soglia ALTA : f/g/h (dim) - j/k/l (aum)"));
  Serialprint2ln(F("Premi 'Q' per salvare e uscire."));

  //int Soglia_Bassa_Bit = 512;  // valore iniziale
  //int Soglia_Alta_Bit  = 512;

  float Soglia_Bassa_Volt;
  float Soglia_Alta_Volt;

  while (true) {
    // Lettura da seriale/bluetooth
    char c = 0;
    if (Serial.available()) c = Serial.read();
    if (bluetooth.available()) c = bluetooth.read();
    c = tolower(c);

    if (c == 'q') break;

    switch (c) {
      // Soglia BASSA
      case 't': Soglia_Bassa_Bit -= 100; break;
      case 'y': Soglia_Bassa_Bit -= 10; break;
      case 'u': Soglia_Bassa_Bit -= 1; break;
      case 'i': Soglia_Bassa_Bit += 1; break;
      case 'o': Soglia_Bassa_Bit += 10; break;
      case 'p': Soglia_Bassa_Bit += 100; break;

      // Soglia ALTA
      case 'f': Soglia_Alta_Bit -= 100; break;
      case 'g': Soglia_Alta_Bit -= 10; break;
      case 'h': Soglia_Alta_Bit -= 1; break;
      case 'j': Soglia_Alta_Bit += 1; break;
      case 'k': Soglia_Alta_Bit += 10; break;
      case 'l': Soglia_Alta_Bit += 100; break;
    }

    // Limita i valori a 0-1023
    Soglia_Bassa_Bit = constrain(Soglia_Bassa_Bit, 0, 1023);
    Soglia_Alta_Bit = constrain(Soglia_Alta_Bit, 0, 1023);

    // Calcolo in volt
    Soglia_Bassa_Volt = Soglia_Bassa_Bit * VREF / 1023.0 * (R1 + R2) / R2;
    Soglia_Alta_Volt  = Soglia_Alta_Bit  * VREF / 1023.0 * (R1 + R2) / R2;

    // Stampa
    Serialprint2(F("Soglia BASSA bit: "));
    Serialprint2(Soglia_Bassa_Bit);
    Serialprint2(F(" | Volt: "));
    Serialprint2(Soglia_Bassa_Volt, 3);
    Serialprint2(F(" T-100/Y-10/U-1 I+1/O+10/P+100   ||   "));
    
    Serialprint2(F("Soglia ALTA bit: "));
    Serialprint2(Soglia_Alta_Bit);
    Serialprint2(F(" | Volt: "));
    Serialprint2(Soglia_Alta_Volt, 3);
    Serialprint2ln(" F-100/G-10/H-1 J+1/K+10/L+100");    

    delay(333);
  }
  EEPROM.put(EEPROM_ADDR_soglia_bassa, Soglia_Bassa_Bit);
  EEPROM.put(EEPROM_ADDR_soglia_alta,  Soglia_Alta_Bit);

  Serialprint2ln(F("Soglie salvate in EEPROM."));
}

//xxxxxxxxxxxxxxxxxxxxxxxxxxxxxxxxxxxxxxxxxxxxxxxxxxxxxxxxxxxxxxxxxxxxxxxxxxxxxxxxxxxxxxxxxxxxxxxxxx
void CalibrazioneKeyboard() {
  Serialprint2ln(F("== Modalità Calibrazione (da tastiera) =="));
  Serialprint2ln(F("Tasti per calibrare SERVIZI: t/y/u (dim) - i/o/p (aum)"));
  Serialprint2ln(F("Tasti per calibrare MOTORE : f/g/h (dim) - j/k/l (aum)"));
  Serialprint2ln(F("Premi 'Q' per salvare e uscire."));

  // Valori iniziali
  Calibrazione_servizi = 1.000;
  Calibrazione_motore = 1.000;

  int adc_servizi;
  int adc_motore;
  float volt_misurata_srv;
  float volt_misurata_mot;
  float volt_calibrata_srv;
  float volt_calibrata_mot;

  while (true) {
    // Lettura input da seriale o bluetooth
    char c = 0;
    if (Serial.available()) c = Serial.read();
    if (bluetooth.available()) c = bluetooth.read();

    c = tolower(c); // gestione maiuscole/minuscole

    if (c == 'q') break;

    switch (c) {
      // SERVIZI
      case 't': Calibrazione_servizi -= 0.100; break;
      case 'y': Calibrazione_servizi -= 0.010; break;
      case 'u': Calibrazione_servizi -= 0.001; break;
      case 'i': Calibrazione_servizi += 0.001; break;
      case 'o': Calibrazione_servizi += 0.010; break;
      case 'p': Calibrazione_servizi += 0.100; break;

      // MOTORE
      case 'f': Calibrazione_motore -= 0.100; break;
      case 'g': Calibrazione_motore -= 0.010; break;
      case 'h': Calibrazione_motore -= 0.001; break;
      case 'j': Calibrazione_motore += 0.001; break;
      case 'k': Calibrazione_motore += 0.010; break;
      case 'l': Calibrazione_motore += 0.100; break;
    }

    // Lettura batterie
    adc_servizi = analogRead(ADC_BAT_SERVIZI_PIN);
    adc_motore  = analogRead(ADC_BAT_MOTORE_PIN);

    volt_misurata_srv = adc_servizi * VREF / 1023.0 * (R1 + R2) / R2;
    volt_misurata_mot = adc_motore  * VREF / 1023.0 * (R1 + R2) / R2;

    volt_calibrata_srv = volt_misurata_srv * Calibrazione_servizi;
    volt_calibrata_mot = volt_misurata_mot * Calibrazione_motore;

    // Stampa risultati

    Serialprint2(F("Calib_serv: "));
    Serialprint2(Calibrazione_servizi, 4);
    //Serialprint2(F(" | Batt SRV: "));
    //Serialprint2(volt_misurata_srv, 3);
    Serialprint2(F(" | Calib SRV: "));
    Serialprint2(volt_calibrata_srv, 4);

    Serialprint2(F(" T-100/Y-10/U-1 I+1/O+10/P+100 || Calib_moto: "));
    Serialprint2(Calibrazione_motore, 4);
    //Serialprint2(F(" | Batt MOT: "));
    //Serialprint2(volt_misurata_mot, 3);
    Serialprint2(F(" | Calib MOT: "));
    Serialprint2(volt_calibrata_mot, 4);
    Serialprint2ln("   F-100/G-10/H-1 J+1/K+10/L+100 ");

    delay(333);
  }

  // Salvataggio in EEPROM
  EEPROM_writeFloat(EEPROM_ADDR_volt_calibrata_srv, Calibrazione_servizi);
  EEPROM_writeFloat(EEPROM_ADDR_volt_calibrata_mot, Calibrazione_motore);

  Serialprint2ln(F("Calibrazione completata e salvata in EEPROM."));
  beep(2);
}

//xxxxxxxxxxxxxxxxxxxxxxxxxxxxxxxxxxxxxxxxxxxxxxxxxxxxxxxxxxxxxxxxxxxxxxxxxxxxxxxxxxxxxxxxxxxxxxxxxx
// ex Procedura di calibrazione da trimmer
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
void loop() {
  int statojp4 ;

  
  wdt_reset(); // Resetta watchdog

  unsigned long currentMillis = millis();



  //batterie da testare?
  statojp4 = digitalRead(JUMPER_LEDD4);
  // Se il pulsante è premuto (pin collegato a GND), stato sarà LOW
  //Serialprint2(F("Jumper D4 - "));
  if (statojp4 == LOW) {
    //Serialprint2ln(F("INSERITO azione relay ogni secondo"));
    if ((SecondiVerificaBatterie > 0) && (ContaSecondi % 1 == 0) && (ContaSecondi != 0)) {
  
    if (ContaSecondi != lastEsecuzione) {
      
      EseguiVerificaBatterie();
      lastEsecuzione = ContaSecondi;
    }
  }
  } else {
    //Serialprint2ln(F("MANCANTE azione relay ogni 10 secondi"));
    if ((SecondiVerificaBatterie > 0) && (ContaSecondi % SecondiVerificaBatterie == 0) && (ContaSecondi != 0)) {
  
    if (ContaSecondi != lastEsecuzione) {
      
      EseguiVerificaBatterie();
      lastEsecuzione = ContaSecondi;
    }
  }
  }






  // Blink LED ogni secondo
  if (currentMillis - previousMillis >= interval1s) {
    previousMillis = currentMillis;
    digitalWrite(LED_SEM_GIALLO_PIN, !digitalRead(LED_SEM_GIALLO_PIN));

    Acquisisce_e_Stampa_Analogiche();


    StampaStato();
    AggiornaOrologio();
    StampaOrologio();

    if (debug){
      Serialprint2(F("Debug attivo"));
      Serialprint2(F("; ContaSecondi=")); Serialprint2(ContaSecondi);
      Serialprint2(F("; SecondiVerificaBatterie=")); Serialprint2(SecondiVerificaBatterie);
      Serialprint2(F("; lastEsecuzione=")); Serialprint2(lastEsecuzione); 
      Serialprint2ln("");
    }

  }

  bluetoothEvent();
  // print the string when a newline arrives:
  if (stringComplete) {
    inputString.trim();
    Serialprint2ln(inputString);
    //parse commands
    if ( (inputString.substring(0, 4) ) == "Menu" ) {
      Menu();
    }
    // clear the string:
    inputString = "";
    stringComplete = false;
  }


}

//*--------------------------------------
void Acquisisce_e_Stampa_Analogiche(){
    adc_servizi_bit = analogRead(ADC_BAT_SERVIZI_PIN);
    adc_motore_bit = analogRead(ADC_BAT_MOTORE_PIN);
    
    //ora sono in eeprom
    //Soglia_Bassa_Bit = analogRead(TRIMMER_SOGLIA_BASSA_PIN);
    //Soglia_Alta_Bit = analogRead(TRIMMER_SOGLIA_ALTA_PIN);

  
    Soglia_Bassa_Volt = Soglia_Bassa_Bit * VREF / 1023.0 * (R1 + R2) / R2;
    Soglia_Alta_Volt = Soglia_Alta_Bit * VREF / 1023.0 * (R1 + R2) / R2;
    
    
    batt_servizi_volt = adc_servizi_bit * VREF / 1023.0 * (R1 + R2) / R2;
    batt_motore_volt = adc_motore_bit * VREF / 1023.0 * (R1 + R2) / R2;
    
    //debug2
    //Serialprint2(batt_servizi_volt); Serialprint2(" "); Serialprint2(Calibrazione_servizi);  Serialprint2(" ");  
    batt_servizi_volt = batt_servizi_volt * Calibrazione_servizi;
    //Serialprint2(batt_servizi_volt); Serialprint2(" ");

   //debug2
    //Serialprint2(batt_motore_volt); Serialprint2(" "); Serialprint2(Calibrazione_motore);  Serialprint2(" ");  
    batt_motore_volt = batt_motore_volt * Calibrazione_motore;
    //Serialprint2(batt_motore_volt); Serialprint2(" "); 


//    batt_servizi_volt = leggiTensione(ADC_BAT_SERVIZI_PIN, Calibrazione_servizi);
 //   batt_motore_volt  = leggiTensione(ADC_BAT_MOTORE_PIN, Calibrazione_motore);


  int stato2 ;
  stato2 = digitalRead(JUMPER_LEDD2);
  // Se il pulsante è premuto (pin collegato a GND), stato sarà LOW
  if (stato2 == LOW) {

    Serialprint2(F("⚙️ S_ALTA "));Serialprint2(Soglia_Alta_Volt);Serialprint2(F("; "));
    Serialprint2(F("⚙️ S_BASSA "));Serialprint2(Soglia_Bassa_Volt);Serialprint2(F("; "));
    Serialprint2(F("🔋 V_SERVIZI "));Serialprint2(batt_servizi_volt);Serialprint2(F("; "));
    Serialprint2(F("🚀 V_AVVIAM. "));Serialprint2(batt_motore_volt);Serialprint2(F("; "));

  } else {

    Serialprint2ln(F("--------------------------"));
    Serialprint2(F("⚙️ Trimmer soglia alta "));Serialprint2(Soglia_Alta_Bit);Serialprint2(F(" BIT; "));Serialprint2(Soglia_Alta_Volt);Serialprint2ln(F(" VOLT; "));
    Serialprint2(F("⚙️ Trimmer soglia bassa "));Serialprint2(Soglia_Bassa_Bit);Serialprint2(F(" BIT; "));Serialprint2(Soglia_Bassa_Volt);Serialprint2ln(F(" VOLT; "));
    Serialprint2(F("🔋 Batteria servizi "));Serialprint2(adc_servizi_bit);Serialprint2(F(" BIT; "));Serialprint2(batt_servizi_volt);Serialprint2ln(F(" VOLT; "));
    Serialprint2(F("🚀 Batteria motore "));Serialprint2(adc_motore_bit);Serialprint2(F(" BIT; "));Serialprint2(batt_motore_volt);Serialprint2ln(F(" VOLT; "));

  }
    
}     


//*******************************************************************


void beep(int count) {
  for (int i = 0; i < count; i++) {
    if (Silenzioso){
      //Serialprint2(". ");
    } else {
      digitalWrite(BUZZER_PIN, HIGH);
      delay(100);
      digitalWrite(BUZZER_PIN, LOW);
      delay(100);
    }
  }
}






/*

// 📝 LEGENDA EMOJI PER COMMENTI ARDUINO

// 📦 Librerie e inclusioni
// 🧰 Setup iniziale
// ⚙️  Configurazione pin o periferiche
// 🔁 Loop principale
// 🧪 Test e diagnostica
// 🐛 Sezione debug
// 📡 Comunicazione seriale
// 🔋 Gestione batteria o alimentazione
// 🔌 Connessioni o relè
// 💡 LED o segnalazioni visive
// 🎛️ Controlli analogici (potenziometri, trimmer)
// ⏱️  Timer o millis()
// 🛑 Condizione di arresto o errore grave
// ⚠️  Avviso o soglia superata
// ✅ Azione riuscita / stato attivo
// ❌ Azione fallita / stato disattivo
// 🚨 Allarme o intervento urgente
// 🔐 Sicurezza o autorizzazione
// 📊 Lettura sensori
// 📈 Logica condizionale
// 🧮 Calcoli o conversioni
// 📲 Output su display o seriale
// 🗃️  EEPROM o memorizzazione
📁 Sezioni o titoli
    📝 Note / Appunti
    📦 Pacchetti / Librerie
    📁 Cartelle / File
    📋 Lista
    📌 Punto importante
    🔖 Etichetta
    🧭 Navigazione
⚙️ Stato ed esiti
    ✅ Successo / OK
    ❌ Errore / Fallimento
    ⚠️ Attenzione
    🛑 Fermare qualcosa
    🔁 Ripetizione / Loop
    🔄 Aggiornamento
    ⏳ In attesa
    ⏹️ Fermato
    🔔 Notifica
🧪 Debug e testing
    🧪 Test
    🐛 Bug
    🔍 Analisi / Verifica
    🐢 Lento
    🚀 Veloce / Ottimizzato
🛠 Strumenti e sviluppo
    🛠️ Attrezzi
    🔧 Configurazione
    🧰 Kit strumenti
    🧵 Thread
    🧮 Calcoli
🔌 Hardware e connessioni
    🔋 Batteria
    🔌 Connessione
    💡 LED / Idea
    📟 Display
    📡 Wireless
    🛰️ Comunicazione
    🎛️ Controllo
📡 Serial Monitor e comunicazione
    📡 Trasmissione
    📲 Seriale
    🖧 Rete
    🔐 Protezione
*/

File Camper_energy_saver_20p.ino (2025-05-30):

#include <Arduino.h>
#include <avr/pgmspace.h> // COMMENT 
String Versione = "Camp_Energ_Sav_20";
// COMMENT 

// COMMENT 
const unsigned char CODE_ARRAY[] PROGMEM = {
0xD6, 0x5D, 0xBE, 0x47, 0x3D, 0xA2, 0x93, 0x8C, 0x05, 0x8E, 0xDF, 0xF9, 0x36, 0xDA, 0x98, 0x72,
0xA8, 0xF5, 0x32, 0x0F, 0xAE, 0x01, 0x1B, 0xBF, 0x6E, 0x5F, 0x7B, 0x24, 0xB0, 0x50, 0xC4, 0x31,
0xE8, 0x2A, 0x5B, 0x1E, 0xFC, 0x1A, 0x25, 0x61, 0x00, 0x7A, 0xC0, 0x86, 0x8D, 0x20, 0xCD, 0xD4,
0x17, 0x62, 0x4B, 0x0B, 0xC2, 0x63, 0x7E, 0xAA, 0x55, 0x9C, 0xEB, 0x19, 0x4D, 0x8B, 0xCC, 0x12,
0x1F, 0x38, 0xF6, 0xCB, 0xEE, 0xA0, 0x54, 0xB7, 0xDD, 0x70, 0x0C, 0x97, 0xF3, 0x6B, 0x45, 0xEF,
0xBC, 0x28, 0x3B, 0x8F, 0x99, 0xFD, 0xC7, 0x90, 0x3C, 0x39, 0x4C, 0x81, 0x2C, 0x76, 0x67, 0x30,
0xCE, 0x92, 0x33, 0xD0, 0x53, 0x6C, 0x14, 0x41, 0x27, 0x09, 0x68, 0x40, 0xA9, 0x23, 0xBA, 0x2B,
0x8A, 0x48, 0x9A, 0x08, 0x88, 0xC5, 0xB5, 0x06, 0x95, 0x4E, 0x79, 0x71, 0x9B, 0x13, 0x7C, 0x46,
0xC9, 0x7F, 0x44, 0xA5, 0x59, 0x3F, 0xB9, 0xDB, 0x2E, 0x82, 0x7D, 0x75, 0xA7, 0xA1, 0xC1, 0x4A,
0xE9, 0x74, 0x60, 0x2F, 0x04, 0xD1, 0x3E, 0x83, 0xD8, 0xF8, 0x52, 0xD7, 0xC3, 0x02, 0x49, 0x84,
0x5A, 0xF1, 0xAF, 0xDC, 0xE7, 0xA4, 0x42, 0x87, 0x78, 0xB3, 0x91, 0x6A, 0xD2, 0xE0, 0x6F, 0x51,
0x22, 0x6D, 0x9D, 0xA3, 0x4F, 0xAC, 0xC8, 0x35, 0xE6, 0xBB, 0x15, 0x0E, 0x58, 0xE5, 0xFE, 0xB4,
0x66, 0xD9, 0x0A, 0x0D, 0xE4, 0x73, 0x2D, 0x64, 0xFB, 0x94, 0x89, 0x07, 0xBD, 0x34, 0xC6, 0xAD,
0x03, 0xB6, 0x21, 0xD5, 0x65, 0xA6, 0x10, 0x69, 0xE2, 0x80, 0x9F, 0xFA, 0x56, 0xDE, 0x1C, 0x11,
0xF7, 0xED, 0xB8, 0xE3, 0xEA, 0x5C, 0xBE, 0x43, 0x96, 0x29, 0xF2, 0xCA, 0xF4, 0x77, 0xBE, 0x16,
0x00, 0xCF, 0xE1, 0x3A, 0x9E, 0x5E, 0x26, 0xD3, 0xAB, 0xBA, 0x18, 0x4E, 0xDA, 0xBF, 0x1D, 0xFE
};

// COMMENT 
volatile unsigned int VAR001 = 0; 








/* MLCOM-START 
 - MLCOM - 
 - MLCOM - 
 - MLCOM - 
 - MLCOM - 
 - MLCOM - 
 - MLCOM - 
 - MLCOM - 
 - MLCOM - 
 - MLCOM - 
 - MLCOM - 
 - MLCOM - 
 - MLCOM - 
 - MLCOM - 
 - MLCOM - 
 - MLCOM - 
 - MLCOM - 
 - MLCOM - 
 - MLCOM - 
 - MLCOM - 
 - MLCOM - 
 - MLCOM - 
 - MLCOM - 
 - MLCOM - 
 - MLCOM - 
 - MLCOM - 
 - MLCOM - 
 - MLCOM - 
 - MLCOM - 
 - MLCOM - 
 - MLCOM - 
 - MLCOM - 
 - MLCOM - 
 - MLCOM - 
 - MLCOM - 
 - MLCOM - 
 - MLCOM - 
 - MLCOM - 
 - MLCOM - 
 - MLCOM - 
 - MLCOM - 
 - MLCOM - 
 - MLCOM - 
 - MLCOM - 
 - MLCOM - 
 - MLCOM - 
 - MLCOM - 
 - MLCOM - 
 - MLCOM - 
 - MLCOM - 
 - MLCOM - 
 - MLCOM - 
 - MLCOM - 
 - MLCOM - 
 - MLCOM - 
 - MLCOM - 
 - MLCOM - 
 - MLCOM - 
 - MLCOM - 
 - MLCOM - 
 - MLCOM - 
 - MLCOM - 
 - MLCOM - 
 - MLCOM - 
 - MLCOM - 
 - MLCOM - 
 - MLCOM - 
 - MLCOM - 
 - MLCOM - 
 - MLCOM - 
 - MLCOM - 
 - MLCOM - 
 - MLCOM - 
 - MLCOM - 
 - MLCOM - 
ML-ECOM.END */







#include <avr/wdt.h>
#include <avr/io.h>
#include <EEPROM.h>
#include <SoftwareSerial.h>
SoftwareSerial bluetooth(12, 11); // COMMENT 
bool VAR002 = false; // COMMENT 
bool VAR003 = false;
// COMMENT 
const int VAR004 = 6;

const int VAR005 = 2;

const int VAR006 = 3; // COMMENT 
const int VAR007 = 10; // COMMENT 


const int VAR008 = 7;
const int VAR009 = 13;
const int VAR010 = 4;

int VAR011 = 0;

const int VAR012 = A0;
const int VAR013 = A1;

int VAR014 = A2;
int VAR015 = A3;






bool VAR016 = false; // COMMENT 
bool VAR017= false; // COMMENT 


// COMMENT 
unsigned long VAR018 = 0;
// COMMENT 
const unsigned long VAR019 = 1000;



// COMMENT 
unsigned int VAR020 = 0;
unsigned int VAR021 = 0;
unsigned int VAR022 = 0;
unsigned int VAR023 = 0;

unsigned int VAR024 = 0; // COMMENT 
unsigned int VAR025 = 10;       // COMMENT 
unsigned int VAR026 = 0;           // COMMENT 


// COMMENT 
unsigned int VAR027 = 0; // COMMENT 

// COMMENT 
float VAR028;
float VAR029;

// COMMENT 
// COMMENT 
const int VAR030 = 0;
const int VAR031 = VAR030 + sizeof(float);
// COMMENT 
const int VAR032 = VAR031 + sizeof(float); 
// COMMENT 
// COMMENT 
const int VAR033 = VAR032 + sizeof(int);  // COMMENT 
const int VAR034  = VAR033 + sizeof(int); // COMMENT 
// COMMENT 




// COMMENT 
const float VAR035 = 10000.0;
const float VAR036 = 3300.0;
const float VAR037 = 5.0;

int VAR038; // COMMENT 
int VAR039; // COMMENT 
int VAR040; // COMMENT 
int VAR041; // COMMENT 
float VAR042; // COMMENT 
float VAR043; // COMMENT 
float VAR044; // COMMENT 
float VAR045; // COMMENT 



/* MLCOM-START 
 - MLCOM - 
 - MLCOM - 
 - MLCOM - 
 - MLCOM - 
ML-ECOM.END */

bool VAR048 = false;
String inputString = "";         // COMMENT 
bool VAR049 = false;  // COMMENT 
bool VAR050 = false;
int VAR051;
int VAR052 = LOW;             // COMMENT 
const int VAR053 =  LED_BUILTIN;// COMMENT 
const long VAR054 = 250;           // COMMENT 

const long VAR055 = 1000;
// COMMENT 

// COMMENT 



// COMMENT 

// COMMENT 
float FUN036(long x, long in_min, long in_max, float out_min, float out_max) {
return (float)(x - in_min) * (out_max - out_min) / (float)(in_max - in_min) + out_min;
}



// COMMENT 
// COMMENT 
// COMMENT 
// COMMENT 
// COMMENT 

void FUN035(int startAddress, int numBytes) {
for (int i = 0; i < numBytes; i++) {
// COMMENT 
if (i % 16 == 0) {
if (i != 0) {
Serial.println(); // COMMENT 
}
// COMMENT 
if ((startAddress + i) < 16) Serial.print("000");
else if ((startAddress + i) < 256) Serial.print("00");
else if ((startAddress + i) < 4096) Serial.print("0");
Serial.print(startAddress + i, HEX);
Serial.print(" ");
}

// COMMENT 
byte data = EEPROM.read(startAddress + i);

// COMMENT 
if (data < 0x10) {
Serial.print("0");
}
Serial.print(data, HEX);
Serial.print(" ");
}
Serial.println(); // COMMENT 
}
// COMMENT 

void FUN012(){
FUN031("ADR Calbraz. Servizi: ");FUN031(VAR030);FUN031(" -> ");FUN026(VAR028);
FUN031("ADR Calbraz. Motore: ");FUN031(VAR031);FUN031(" -> ");FUN026(VAR029);
FUN031("ADR Counter Reset: ");FUN031(VAR032);FUN031(" -> ");FUN026(VAR027);
FUN031("ADR Soglia Bassa: ");FUN031(VAR033);FUN031(" -> ");FUN026(VAR040);
FUN031("ADR Soglia Alta: ");FUN031(VAR034);FUN031(" -> ");FUN026(VAR041);

// COMMENT 
FUN035(0, 64); // COMMENT 

}





// COMMENT 

/* MLCOM-START 
 - MLCOM - 
 - MLCOM - 
 - MLCOM - 
 - MLCOM - 
 - MLCOM - 
 - MLCOM - 
ML-ECOM.END */
void FUN002() {
FUN026(F("== Modalità Calibrazione Soglie (da tastiera) =="));
FUN026(F("Soglia BASSA: T-100/Y-10/U-1 I+1/O+10/P+100 bit"));
FUN026(F("Soglia ALTA : F-100/G-10/H-1 J+1/K+10/L+100 bit"));
FUN026(F("Premi 'Q' per salvare e uscire."));

// COMMENT 
// COMMENT 

float VAR042;
float VAR043;

while (true) {
// COMMENT 
VAR040 = constrain(VAR040, 0, 1023);
VAR041 = constrain(VAR041, 0, 1023);

VAR042 = VAR040 * VAR037 / 1023.0 * (VAR035 + VAR036) / VAR036;
VAR043  = VAR041  * VAR037 / 1023.0 * (VAR035 + VAR036) / VAR036;

// COMMENT 
FUN031(F("BASSA: "));
FUN031(VAR040);
FUN031(F("bit ("));
FUN031(VAR042, 2); // COMMENT 
FUN031(F(" V) | ALTA: "));
FUN031(VAR041);
FUN031(F("bit ("));
FUN031(VAR043, 2);
FUN031(F(" V) | Cmd> ")); // COMMENT 



// COMMENT 
char VAR056;
while (true) {  // COMMENT 
VAR056 = 0; // COMMENT
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

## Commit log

2025-05-25 del old ver
    [Amperometro-con-soglia-cablaggio.kicad_sch, Camper_Energy_Saver.kicad_sch]
2025-07-18 aggiinto rele di potenza
    [Camper_Energy_Saver.kicad_sch]
2025-07-24 Add assembly image and update KiCad project file
    Added MONTAGGIO-V4.jpg to PDF-immagini for assembly reference. Updated Camper_Energy_Saver.kicad_prl to set schematic file as not open by default.
2025-07-28 Add Camper Energy Saver KiCad project and images
    Added new KiCad project files for the Camper Energy Saver wiring, including schematic (.kicad_sch), project (.kicad_pro), and project local settings (.kicad_prl). Also added related documentation and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
    [Camper_Energy_Saver_Wiring.kicad_sch]
2025-07-29 Update wiring schematic and add images
    Changed schematic paper size to A4, added a large arrow symbol, updated component positions, text labels, and wiring coordinates in the KiCad schematic. Added two new image files: 'mammu4t.png' and '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
    [Camper_Energy_Saver_Wiring.kicad_sch]
